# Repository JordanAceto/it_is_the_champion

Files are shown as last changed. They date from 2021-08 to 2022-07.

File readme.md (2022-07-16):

# 15 Watt Single Ended Tube Guitar Amp

- ## GU50 Pentode output
- ## Trainwreck style preamp
- ## It is the champion

---

## [SCHEMATIC](https://github.com/JordanAceto/it_is_the_champion/blob/main/pcb/docs/it_is_the_champion-schematic.pdf)

---
A prototype has been constructed and evaluated using a 6550 output tube. See the [prototype write up](https://github.com/JordanAceto/it_is_the_champion/blob/main/prototype/it_is_the_champion_prototype_write_up.pdf) for details. It sounds pretty good to me.

The GU50 output stage has been breadboarded. It seems to work well and gives a smidge more power out than the 6550 (I'm mostly just using it to be a hipster though).

Next steps:

Task | Status |
---------|--------------|
Schematic capture | &#9745;
PCB layout | &#9745;
Order boards and do test build | &#9745;
Front and rear panels | &#9745;
Generate complete BOM | &#9744;

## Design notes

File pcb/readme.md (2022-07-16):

# Kicad documents for the schematics and PCB layout

## The system consists of:
- ### Power supply PCB
- ### Preamp PCB
- ### Point to point wired power amp
- ### Chassis mount components (transformers, jacks, pots, etc)

The preamp and power supply pcbs are connected with breakaway mousebites.

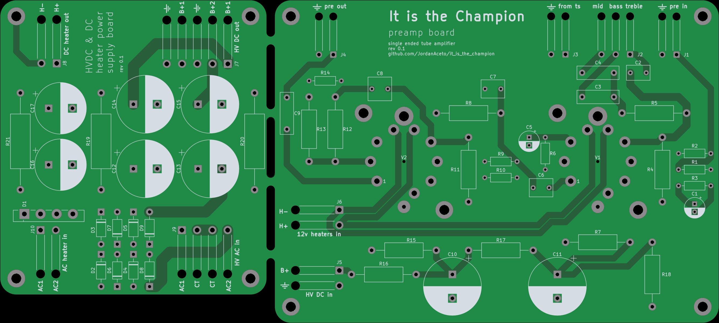
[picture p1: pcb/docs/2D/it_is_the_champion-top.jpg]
pcb


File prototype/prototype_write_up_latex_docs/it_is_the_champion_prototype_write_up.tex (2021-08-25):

\documentclass[pdftex,letterpaper,11pt]{article}
\usepackage[top=1in,bottom=1in,left=1in,right=1in]{geometry}

\usepackage[dvips]{graphicx}
\usepackage{amsmath}
\usepackage{amssymb}
\usepackage{color}
\usepackage[yyyymmdd]{datetime}
\usepackage{fancyhdr}
\usepackage{fancyvrb}
\usepackage[hidelinks]{hyperref}
\usepackage{pslatex}

\usepackage{subfig}
\usepackage{graphicx}
\usepackage[cache=false]{minted}

\usepackage{fancyhdr}
\usepackage{poemscol}
\usepackage{lmodern}

\pagestyle{fancy}

\title{%
	It is the Champion \\
	\large Prototype findings}

\author{Jordan Aceto}

\setlength{\parindent}{0mm}
\setlength{\parskip}{3mm}

\lfoot{Jordan Aceto}
\cfoot{Page \thepage}
\rfoot{PDF: \today, \currenttime}

\renewcommand{\footrulewidth}{0.4pt}

\begin{document}

\maketitle

\tableofcontents

\newpage

\section{Basic Features}

\begin{itemize}
\item Made of mostly ``junk box'' parts.
\item Single ended 6550 ouput stage, cathode biased.
\item Two 12AX7 tubes in the preamp.
\item Fairly high gain ``Trainwreck-ish'' preamp with four gain stages.
\item Conventional treble, middle, bass tone stack.
\item Gain and master volume controls.
\item Point to point wiring in a gutted Fender Vibro-Champ XD cabinet.
\item Power transformer: Hammond 276x.
\item Output transformer: Edcor GXSE15-8-3.5k
\item DC filaments for the first 12AX7, supplied by a separate Antek AN-0115 transformer.
\end{itemize}

\newpage

\section{Preamp}

The preamp is fairly similar to the ``Trainwreck'' circuit. It has the plate driven tone stack early on in the signal path, followed by a gain stage, and then a cold-clipper stage. Since this is a single ended amp without a phase inverter, an additional gain stage is used before the master volume for some extra crunch.

I tweaked some of the values in the tone stack, and added a treble-cut capacitor (C7) to tame some of the ``breaking glass'' high frequencies. This went into a combo with a Warehouse Speakers Veteran-10 10" speaker. The speaker is pretty bright already, so some of the tweaks were implemented to tame exessive treble. If a different speaker is used, I would recommend messing with the tone stack and frequency shaping components to taste.

\begin{figure}[H]
\centering
\caption{Pre-amp circuit}
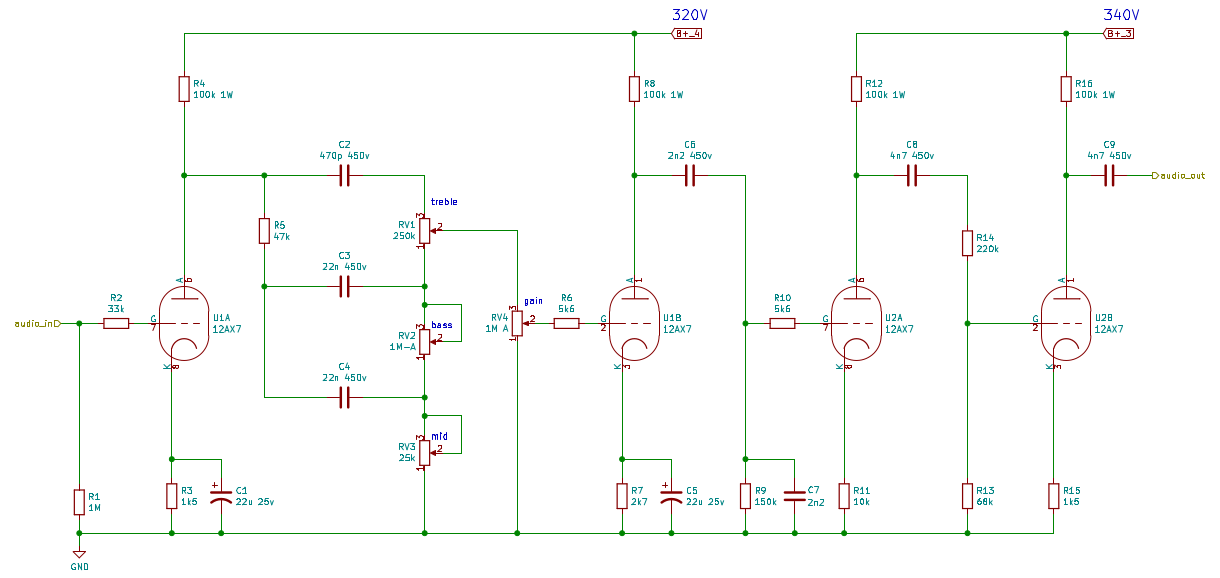
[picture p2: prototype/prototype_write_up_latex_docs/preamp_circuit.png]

\end{figure}

Notable features of this preamp are the tone shaping before the distortion, and small value coupling caps which shave bass frequencies. This circuit is pretty bright and ``cutting'', with enough gain for lots of preamp distortion. It can't quite do modern high-gain metal tones, but it does get pretty darn crunchy. It cleans up very well with the gain control set low, and using the volume control on your guitar is effective for doing the ``clean to mean'' thing. 

Both the clean and distorted tones sound great to me. It has lots of sustain and harmonic richness. It can tend towards overly bright and brittle tones, but adjusting the treble control, the tone pot on your guitar, and pick attack can mitigate this. The bright and cutting sounds can also help the guitar sit well in a mix.

\section{Power Amp}

The single 6550 output tube was chosen to provide a little more ``oomph'' than a typical Champ-style single ended amp, but still be fairly low power for playing at home or in the studio at reasonable volumes. I was looking for about 8 to 10 watts of clean output power, and about 15 watts when heavily overdriven.

\begin{figure}[H]
\centering
\caption{Power amp circuit}
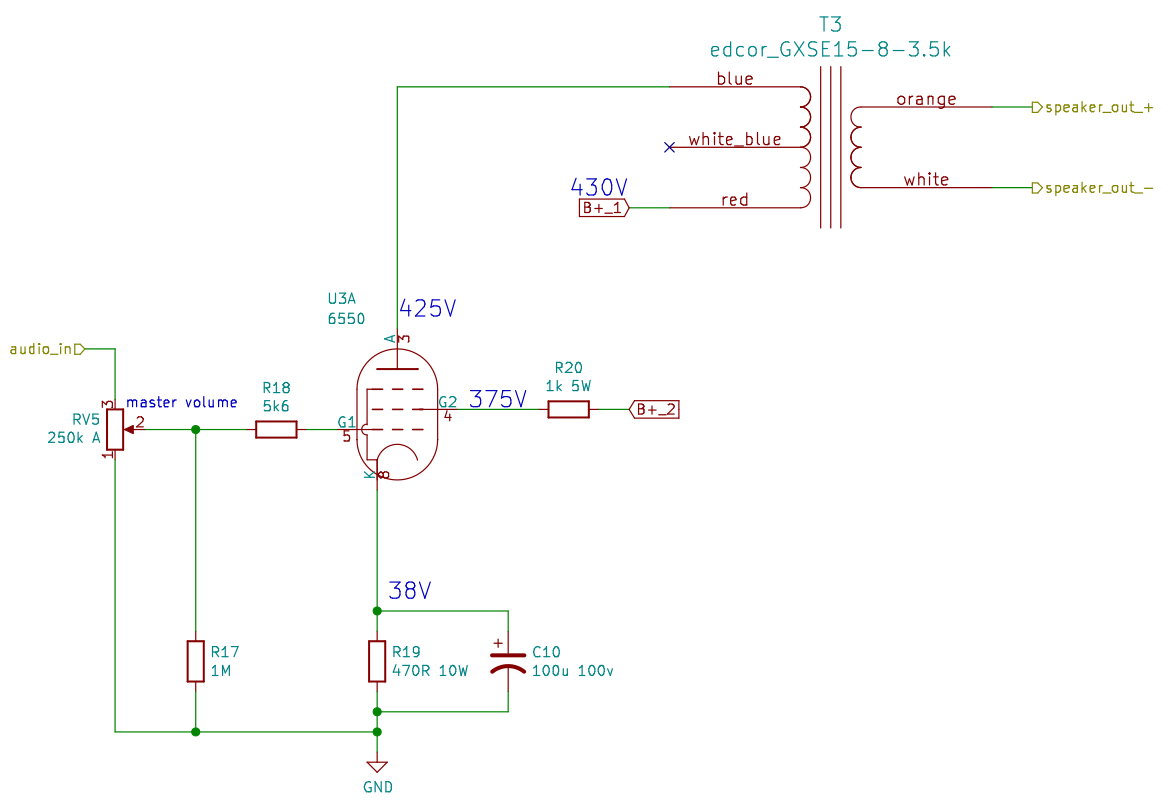
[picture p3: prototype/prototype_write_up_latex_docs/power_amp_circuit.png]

\end{figure}

As we can see by examining the voltage across the cathode resistor, about $80mA$ of bias current flows in the power tube at idle, for about 31 watts of dissipation. The maximum plate dissipation for this tube is 35 watts. I could probably bump up the bias current a little bit, there is no compelling reason to do so for now. 

Erring on the cold side will increase tube life and decrease heat in the chassis. Large output swings will be a little bit asymmetric and will introduce a little DC current in the output transformer, but the OT can handle it and a little asymmety sounds good for overdriven guitar sounds.

After construction, the amp was hooked up to a dummy load to test the power output. The output transformer has a 438:1 impedance ratio, and a variety of load resistances were tried out to experiment with the relationship between load impedance and power delivery. I have a big honkin' dummy load made up of a string of eight 2$\Omega$ resistors, and this allowed me to vary the load resistance, and thus the reflected primary impedance, by clipping heavy test leads across various resistors. The findings are summarized in the table below:

\begin{table}[H]
\centering
\begin{tabular}{ c | c | c }
    Load resistance  & Reflected impedance & Power out (Watts)  \\ \hline \hline
	4 & 1750 & 5.8 \\ \hline
	6 & 2628 & 8.5 \\ \hline
	8 & 3500 & 9.7 \\ \hline
	10 & 4380 & 10 \\ \hline
	12 & 5256 & 9.2 \\ \hline
	14 & 6132 & 8.8 \\ \hline
	16 & 7008 & 7.9 \\ \hline
\end{tabular}
\end{table}

The measured power output is an approximation and shouldn't be taken as a super precise measurement. I adjusted the signal to \textit{just} under the point of clipping while measuring the power output for each impedance, but this is a guitar amp and there is significant nonlinearity well below clipping. The exact point where ``clean signal'' stops and ``clipping'' begins is a soft and blurry line, but I tried to at least keep things reasonably consistent between readings. 

The above table shows us that somewhere around 3.5k to 5k is a happy primary impedance for this circuit if we want to get the most out of the setup as it is. The 3.5k$\Omega$ primary impedace from the output transformer I had lying around seems OK. With experimentation, we could tweak the B+ supply and the load to maximize power out, but a watt or two in either direction isn't going to make or break the amp.

The distortion introduced by overdriving the power amp is quite pleasant, with a gradual introduction of compression, then crunch, then heavy distortion. This is illustrated in the oscilloscope shots below:

\begin{figure}[H]
    \centering
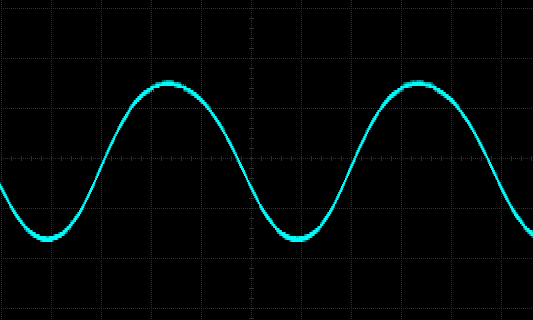
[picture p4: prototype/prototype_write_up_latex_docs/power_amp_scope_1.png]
    \subfloat[\centering]{{ }}
    \qquad
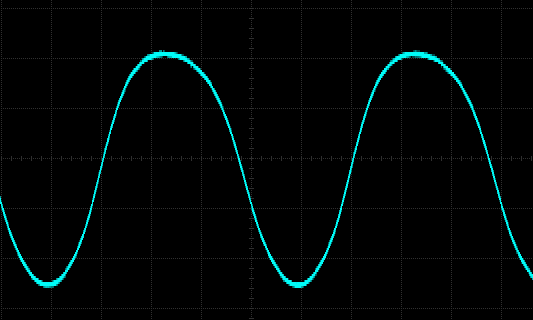
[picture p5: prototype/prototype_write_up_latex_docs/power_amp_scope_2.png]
    \subfloat[\centering]{{ }}
    
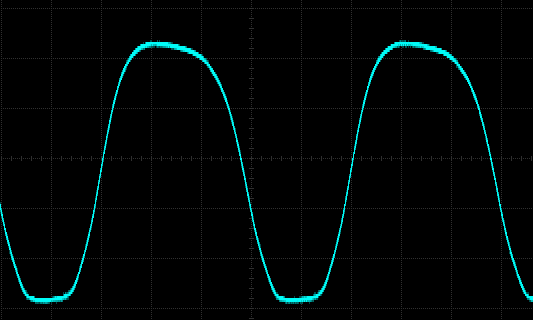
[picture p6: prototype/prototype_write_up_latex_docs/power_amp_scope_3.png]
    \subfloat[\centering]{{ }}
    \qquad
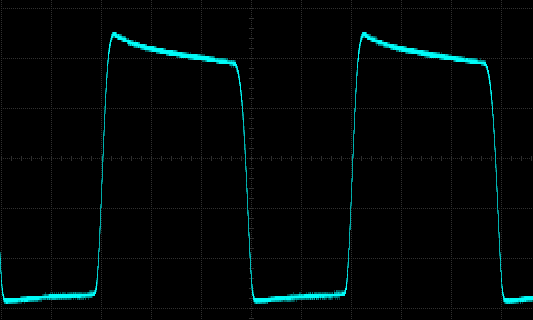
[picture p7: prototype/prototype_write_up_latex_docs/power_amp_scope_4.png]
    \subfloat[\centering]{{ }}
\end{figure}

The asymmetric nature of the distortion is mostly due to the somewhat cold bias current. To me, the circuit sounds good and hits the desired output power, so there is little motivation to try to bring it right into the center of class A or squeeze every last clean milliwatt out of it.

The final output power delivered into an 8 $\Omega$ load is about 10 watts at ``somewhere below five percent'' distortion, and about 15 watts when hard clipping, right on target. I don't have the equipment to accurately measure distortion, so the clean output was ``eyeballed''. IMO, this is good enough for guitar work.

\section{Power supply}

The basic power supply plan is fairly standard, but the power transformer was scavanged from the bin so I had to futz around a little bit. The Hammond power transformer used only has a 115 volt primary winding. This caused all of the secondary voltages to come out a bit high when fed from a modern 120 volt wall outlet. 

To keep the B+ reasonable and, more importantly, to keep the heater voltage in spec, I used the 5 volt winding in ``bucking'' configuration  in series with the primary to reduce all secondary voltages a little bit. Modern Hammond transformers have improved the primary windings to be more compatible with modern wall voltages, but this trick was used so that I could use up an old dust bin transformer which was otherwise suitable.

\begin{figure}[H]
\centering
\caption{Main power supply}
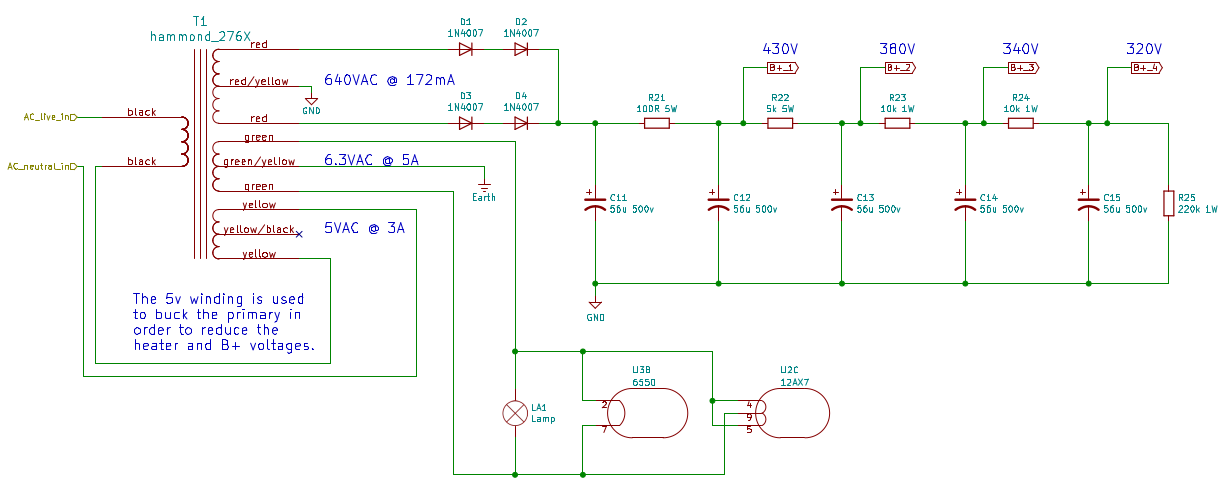
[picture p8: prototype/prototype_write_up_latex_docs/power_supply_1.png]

\end{figure}

After construction, the amp sounded pretty good and the noise performance was quite acceptable. But there was a small amount of 60/120Hz AC buzz coming from the first stage. Since there is so much gain in the preamp, a small amount of noise can become annoying when you crank the gain. I've heard much worse from popular amps, but since this is a hobby project I can afford to spend some effort improving the noise performance. To get things really quiet, I decided to use a DC heater supply for the first 12AX7 tube.

I initially tried to rectify the existing 6 volt winding and use the smoothed DC for just the first tube. This did improve the buzz coming from the first gain stage, but it worsened the buzz coming from the second preamp tube. This is a common problem when trying to do DC heaters as simply as possible, especially in a small chassis. The rectification causes the existing AC supply to become more distorted, and high frequency components are injected into the signal path.

To get things really quiet, I added a small transformer to create a DC heater supply just for V1. I used a small 15 volt transformer that I had kicking around for this. The 15 volts AC is fed into a bridge rectifier, then smoothed with a large capacitor, then fed into an RC filter wich provides further ripple reduction and drops the voltage to right around 12.6 volts DC when loaded with a single 12AX7 heater wired for 12 volt operation.

\begin{figure}[H]
\centering
\caption{DC heater supply for V1}
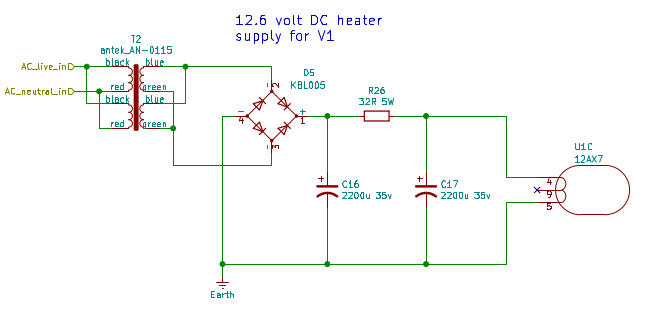
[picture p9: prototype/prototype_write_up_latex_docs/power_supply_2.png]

\end{figure}

With the first tube heater supplied by this smooth DC voltage generated from a different widing than the rest of the 6 volt AC heaters, the amp has very good noise performance. There is some white-noise-ish hiss and a very small amount of power line frequency buzz when the gain control and master volume are both set very high, but this is to be expected in any high gain tube circuit. Most importantly to me, the noise is dominated by hiss, with very low levels of 60 Hz related hum and buzz.

\section{Construction}

The amp was built in the carcass of a Fender Vibro-Champ XD amp that a local guitar store was throwing away. I stripped everything out of the chassis and drilled most of the threaded standoffs out.

The circuit is all point-to-point construction using terminal strips. The tubes are layed out so that the signal path is very straghtforward and signal wires don't meander all over the chassis. Noisy rectifiers and heaters are kept far from sensitive audio nodes.

\begin{figure}[H]
\centering
\caption{Guts}
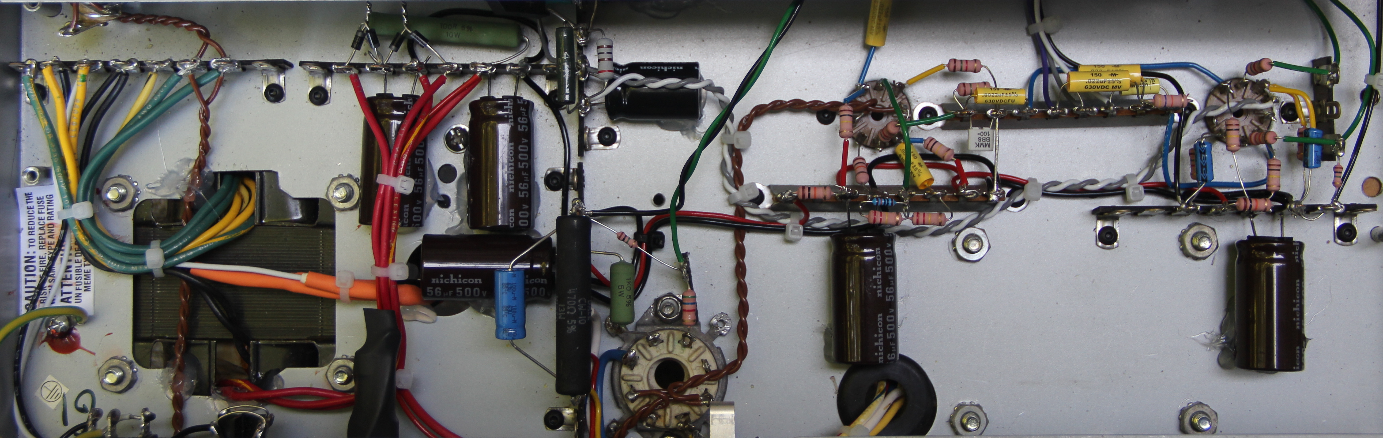
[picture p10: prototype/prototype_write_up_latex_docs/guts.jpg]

\end{figure}

The chassis does get quite hot. The 6550 power tube is dissipating around 30 watts, and its heat rises straight up into the chassis. There are a handful more watts inside the chassis, mostly in the cathode bias resistor for the power tube and the dropping resistor for the DC heater supply.

This is a tube amp though, so hot and toasty is to be expected. None of the components are overly stressed, and reliablility should be quite good. Due to the point-to-point construction, repairs and mods are somewhat annoying to perform, but infinitely possible.

The original Fender donor combo amp came with an 8" speaker, which is just too small for serious guitar sounds at all but the lowest volumes. Additionally, the baffle was made of really cheesy particle board. I made a new baffle out of decent 1/2" plywood with a cutout for a 10" speaker and reapplied the old grill cloth. The Warehouse Vet-10 10" speaker \textit{juuuuuust} fits, other speakers may or may not fit at all. 

The power tube is very close to the magnet, and the spring tube retainer I installed occasionally rattles sympathetically at loud volumes. This is not a major problem, I'll leave it for now and reasses if it becomes annoying later.

\section{Conclusion}

This prototype is a definte success. The noise performance is very good and the power output is right where I wanted it to be. The sound is very nice. There is a range of sparkly cleans, crunchy, and fuzzy sounds in there. The prototype would be perform very well as a practice amp at home, and would probably record pretty well.

The limiting factor is mainly the lame tiny MDF cabinet. Repurposing the dead Fender combo was economical, but a slightly larger cabinet made of better materials would be an improvement. The amp would be pretty at home in a Princeton sized cabinet if another one is made. This would allow for trying out different 10" speakers without worrying about the magnet coming into contact with the power tube.

The next step would be to build another version with selected, instead of stumbled upon, parts. I've layed out a pcb for the preamp and chosen some transformers that I think will work. Unfortunately this will probably be on hold for a while, as the semester is starting up and I won't have much time for fun hobbies until winter break.

\section{About the Name}

When I used to repair tube amplifiers, it was common for the various ``Champs'' to come through the shop for servicing. There is the Fender Champ, the Champion, the Vibro-Champ, the Super-Champ, the list goes on. Whenever I had one of these on my bench, I would always sing to it:

\begin{poem}
\begin{stanza}
You are the Champion\verseline
My frie-end\verseline
And you'll keep on fighting\verseline
Til the end\end{stanza}

\begin{stanza}
You are the Champion\verseline
You are the Champion\verseline
No time for losers\verseline
Cause you are the Champion\end{stanza}
... etc
\end{poem}

Since this amp roughly occupies ``Champ'' territory, only with more output power and with a much meatier preamp, naturally \textbf{It is the Champion}.

\end{document}

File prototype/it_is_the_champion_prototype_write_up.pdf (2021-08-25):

## It is the Champion

Prototype findings

Jordan Aceto

2021/08/25

## Contents

1 Basic Features | 2
2 Preamp | 2
3 Power Amp | 3
4 Power supply | 6
5 Construction | 7
6 Conclusion | 8
7 About the Name | 9

## 1 Basic Features

- Made of mostly “junk box” parts.
- Single ended 6550 ouput stage, cathode biased.
- Two 12AX7 tubes in the preamp.
- Fairly high gain “Trainwreck-ish” preamp with four gain stages.
- Conventional treble, middle, bass tone stack.
- Gain and master volume controls.
- Point to point wiring in a gutted Fender Vibro-Champ XD cabinet.
- Power transformer: Hammond 276x.
- Output transformer: Edcor GXSE15-8-3.5k
- DC filaments for the first 12AX7, supplied by a separate Antek AN-0115 transformer.
Jordan Aceto | Page 2 | PDF: 2021/08/25, 07:26

## 2 Preamp

The preamp is fairly similar to the “Trainwreck” circuit. It has the plate driven tone stack early on in the signal path, followed by a gain stage, and then a cold-clipper stage. Since this is a single ended amp without a phase inverter, an additional gain stage is used before the master volume for some extra crunch.

I tweaked some of the values in the tone stack, and added a treble-cut capacitor (C7) to tame some of the “breaking glass” high frequencies. This went into a combo with a Warehouse Speakers Veteran-10 10” speaker. The speaker is pretty bright already, so some of the tweaks were implemented to tame exessive treble. If a different speaker is used, I would recommend messing with the tone stack and frequency shaping components to taste.

Figure 1: Pre-amp circuit


Notable features of this preamp are the tone shaping before the distortion, and small value coupling caps which shave bass frequencies. This circuit is pretty bright and “cutting”, with enough gain for lots of preamp distortion. It can’t quite do modern high-gain metal tones, but it does get pretty darn crunchy. It cleans up very well with the gain control set low, and using the volume control on your guitar is effective for doing the “clean to mean” thing.

Both the clean and distorted tones sound great to me. It has lots of sustain and harmonic richness. It can tend towards overly bright and brittle tones, but adjusting the treble control, the tone pot on your guitar, and pick attack can mitigate this. The bright and cutting sounds can also help the guitar sit well in a mix.

Jordan Aceto | Page 3 | PDF: 2021/08/25, 07:26

## 3 Power Amp

The single 6550 output tube was chosen to provide a little more “oomph” than a typical Champ-style single ended amp, but still be fairly low power for playing at home or in the studio at reasonable volumes. I was looking for about 8 to 10 watts of clean output power, and about 15 watts when heavily overdriven.

Figure 2: Power amp circuit


As we can see by examining the voltage across the cathode resistor, about 80mA of bias current flows in the power tube at idle, for about 31 watts of dissipation. The maximum plate dissipation for this tube is 35 watts. I could probably bump up the bias current a little bit, there is no compelling reason to do so for now.

Erring on the cold side will increase tube life and decrease heat in the chassis. Large output swings will be a little bit asymmetric and will introduce a little DC current in the output transformer, but the OT can handle it and a little asymmety sounds good for overdriven guitar sounds.

After construction, the amp was hooked up to a dummy load to test the power output. The output transformer has a 438:1 impedance ratio, and a variety of load resistances were tried out to experiment with the relationship between load impedance and power delivery. I have a big honkin’ dummy load made up of a string of eight 2Ω resistors, and this allowed me to vary the load resistance, and thus the reflected primary impedance, by clipping heavy test leads across various

Jordan Aceto | Page 4 | PDF: 2021/08/25, 07:26

resistors. The findings are summarized in the table below:

Load resistance | Reflected impedance | Power out (Watts)
4 | 1750 | 5.8
6 | 2628 | 8.5
8 | 3500 | 9.7
10 | 4380 | 10
12 | 5256 | 9.2
14 | 6132 | 8.8
16 | 7008 | 7.9

The measured power output is an approximation and shouldn’t be taken as a super precise measurement. I adjusted the signal to just under the point of clipping while measuring the power output for each impedance, but this is a guitar amp and there is significant nonlinearity well below clipping. The exact point where “clean signal” stops and “clipping” begins is a soft and blurry line, but I tried to at least keep things reasonably consistent between readings.

The above table shows us that somewhere around 3.5k to 5k is a happy primary impedance for this circuit if we want to get the most out of the setup as it is. The 3.5kΩ primary impedace from the output transformer I had lying around seems OK. With experimentation, we could tweak the B+ supply and the load to maximize power out, but a watt or two in either direction isn’t going to make or break the amp.

The distortion introduced by overdriving the power amp is quite pleasant, with a gradual introduction of compression, then crunch, then heavy distortion. This is illustrated in the oscilloscope shots below:

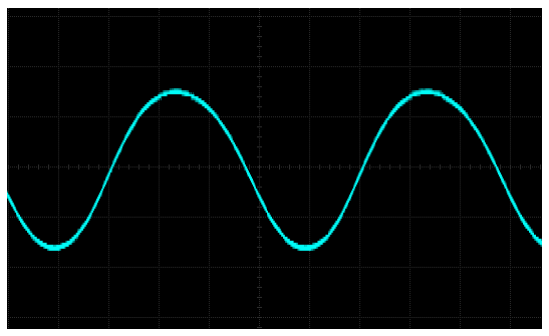
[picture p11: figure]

(a) (b)

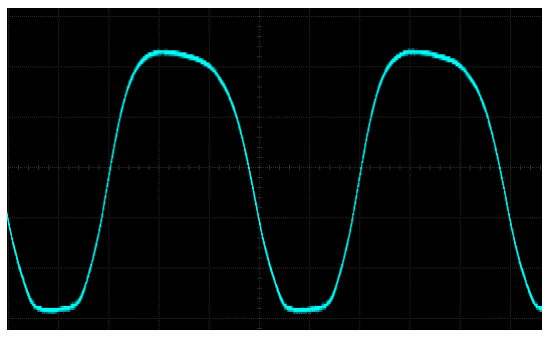
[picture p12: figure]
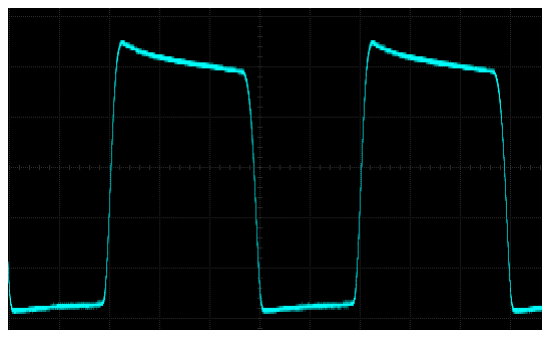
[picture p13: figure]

(c) (d)
Jordan Aceto | Page 5 | PDF: 2021/08/25, 07:26

The asymmetric nature of the distortion is mostly due to the somewhat cold bias current. To me, the circuit sounds good and hits the desired output power, so there is little motivation to try to bring it right into the center of class A or squeeze every last clean milliwatt out of it.

The final output power delivered into an 8 Ω load is about 10 watts at “somewhere below five percent” distortion, and about 15 watts when hard clipping, right on target. I don’t have the equipment to accurately measure distortion, so the clean output was “eyeballed”. IMO, this is good enough for guitar work.

## 4 Power supply

The basic power supply plan is fairly standard, but the power transformer was scavanged from the bin so I had to futz around a little bit. The Hammond power transformer used only has a 115 volt primary winding. This caused all of the secondary voltages to come out a bit high when fed from a modern 120 volt wall outlet.

To keep the B+ reasonable and, more importantly, to keep the heater voltage in spec, I used the 5 volt winding in “bucking” configuration in series with the primary to reduce all secondary voltages a little bit. Modern Hammond transformers have improved the primary windings to be more compatible with modern wall voltages, but this trick was used so that I could use up an old dust bin transformer which was otherwise suitable.

Figure 3: Main power supply

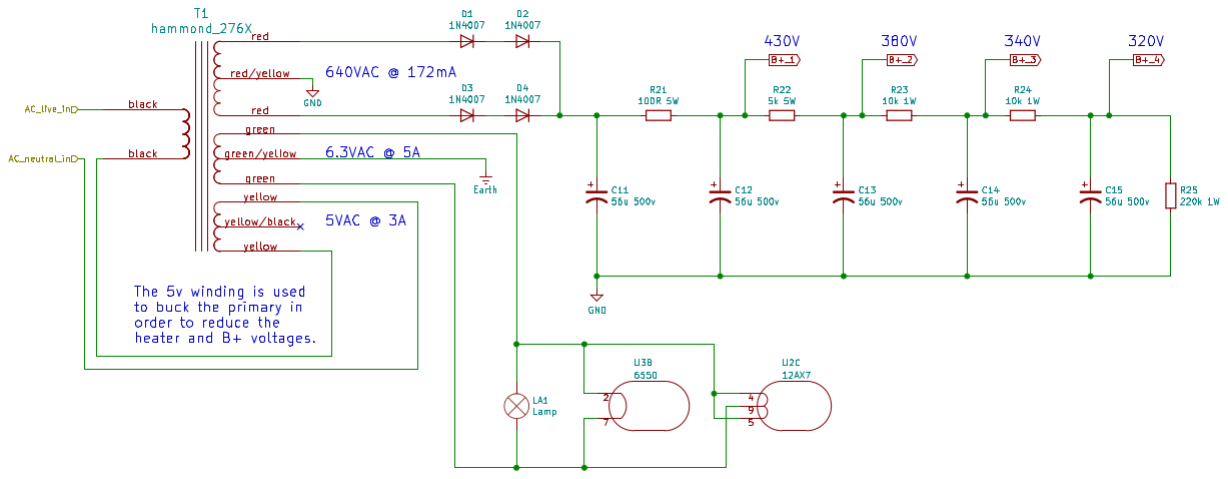
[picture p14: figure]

After construction, the amp sounded pretty good and the noise performance was quite acceptable. But there was a small amount of 60/120Hz AC buzz coming from the first stage. Since there is so much gain in the preamp, a small amount of noise can become annoying when you crank the gain. I’ve heard much worse from popular amps, but since this is a hobby project I can afford to spend some effort improving the noise performance. To get things really quiet, I decided to use a DC heater supply for the first 12AX7 tube.

I initially tried to rectify the existing 6 volt winding and use the smoothed DC for just the first

Jordan Aceto | Page 6 | PDF: 2021/08/25, 07:26

tube. This did improve the buzz coming from the first gain stage, but it worsened the buzz coming from the second preamp tube. This is a common problem when trying to do DC heaters as simply as possible, especially in a small chassis. The rectification causes the existing AC supply to become more distorted, and high frequency components are injected into the signal path.

To get things really quiet, I added a small transformer to create a DC heater supply just for V1. I used a small 15 volt transformer that I had kicking around for this. The 15 volts AC is fed into a bridge rectifier, then smoothed with a large capacitor, then fed into an RC filter wich provides further ripple reduction and drops the voltage to right around 12.6 volts DC when loaded with a single 12AX7 heater wired for 12 volt operation.

Figure 4: DC heater supply for V1


With the first tube heater supplied by this smooth DC voltage generated from a different widing than the rest of the 6 volt AC heaters, the amp has very good noise performance. There is some white-noise-ish hiss and a very small amount of power line frequency buzz when the gain control and master volume are both set very high, but this is to be expected in any high gain tube circuit. Most importantly to me, the noise is dominated by hiss, with very low levels of 60 Hz related hum and buzz.

## 5 Construction

The amp was built in the carcass of a Fender Vibro-Champ XD amp that a local guitar store was throwing away. I stripped everything out of the chassis and drilled most of the threaded standoffs out.

The circuit is all point-to-point construction using terminal strips. The tubes are layed out so that the signal path is very straghtforward and signal wires don’t meander all over the chassis. Noisy rectifiers and heaters are kept far from sensitive audio nodes.

Jordan Aceto | Page 7 | PDF: 2021/08/25, 07:26

Figure 5: Guts


The chassis does get quite hot. The 6550 power tube is dissipating around 30 watts, and its heat rises straight up into the chassis. There are a handful more watts inside the chassis, mostly in the cathode bias resistor for the power tube and the dropping resistor for the DC heater supply.

This is a tube amp though, so hot and toasty is to be expected. None of the components are overly stressed, and reliablility should be quite good. Due to the point-to-point construction, repairs and mods are somewhat annoying to perform, but infinitely possible.

The original Fender donor combo amp came with an 8” speaker, which is just too small for serious guitar sounds at all but the lowest volumes. Additionally, the baffle was made of really cheesy particle board. I made a new baffle out of decent 1/2” plywood with a cutout for a 10” speaker and reapplied the old grill cloth. The Warehouse Vet-10 10” speaker juuuuuust fits, other speakers may or may not fit at all.

The power tube is very close to the magnet, and the spring tube retainer I installed occasionally rattles sympathetically at loud volumes. This is not a major problem, I’ll leave it for now and reasses if it becomes annoying later.

## 6 Conclusion

This prototype is a definte success. The noise performance is very good and the power output is right where I wanted it to be. The sound is very nice. There is a range of sparkly cleans, crunchy, and fuzzy sounds in there. The prototype would be perform very well as a practice amp at home, and would probably record pretty well.

The limiting factor is mainly the lame tiny MDF cabinet. Repurposing the dead Fender combo was economical, but a slightly larger cabinet made of better materials would be an improvement. The amp would be pretty at home in a Princeton sized cabinet if another one is made. This would allow for trying out different 10” speakers without worrying about the magnet coming into contact with the power tube.

The next step would be to build another version with selected, instead of stumbled upon, parts. I’ve layed out a pcb for the preamp and chosen some transformers that I think will work. Unfortunately this will probably be on hold for a while, as the semester is starting up and I won’t have much time

Jordan Aceto | Page 8 | PDF: 2021/08/25, 07:26

for fun hobbies until winter break.

## 7 About the Name

When I used to repair tube amplifiers, it was common for the various “Champs” to come through the shop for servicing. There is the Fender Champ, the Champion, the Vibro-Champ, the Super-Champ, the list goes on. Whenever I had one of these on my bench, I would always sing to it:

You are the Champion
My frie-end
And you’ll keep on fighting Til the end

You are the Champion
You are the Champion
No time for losers
Cause you are the Champion

... etc

Since this amp roughly occupies “Champ” territory, only with more output power and with a much meatier preamp, naturally It is the Champion.

Jordan Aceto | Page 9 | PDF: 2021/08/25, 07:26

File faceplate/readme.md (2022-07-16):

# Cheap and cheerful faceplate option

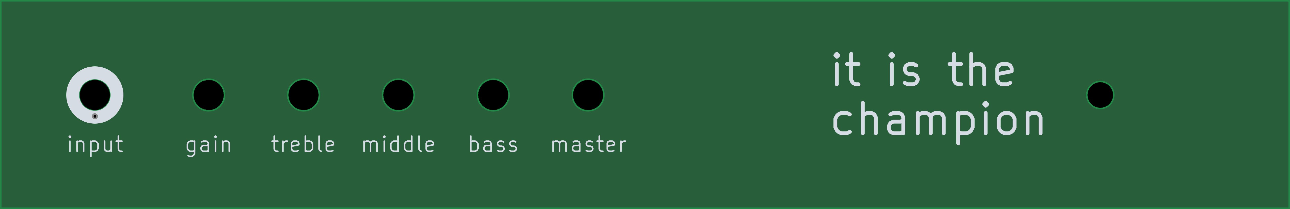
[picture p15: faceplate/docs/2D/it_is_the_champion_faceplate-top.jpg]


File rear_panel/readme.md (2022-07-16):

# Cheap and cheerful rear panel option

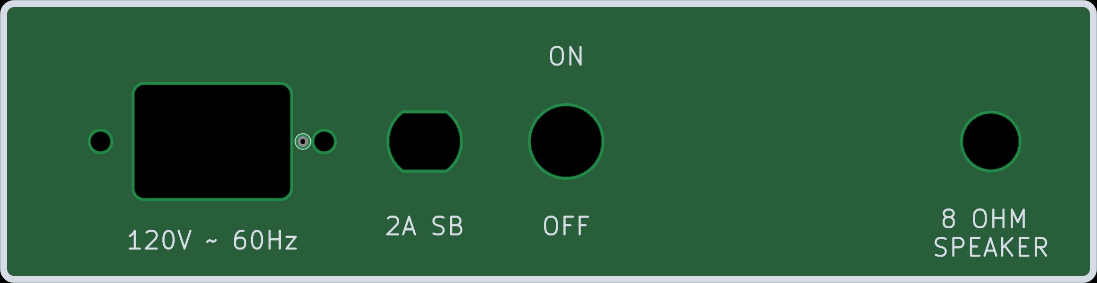
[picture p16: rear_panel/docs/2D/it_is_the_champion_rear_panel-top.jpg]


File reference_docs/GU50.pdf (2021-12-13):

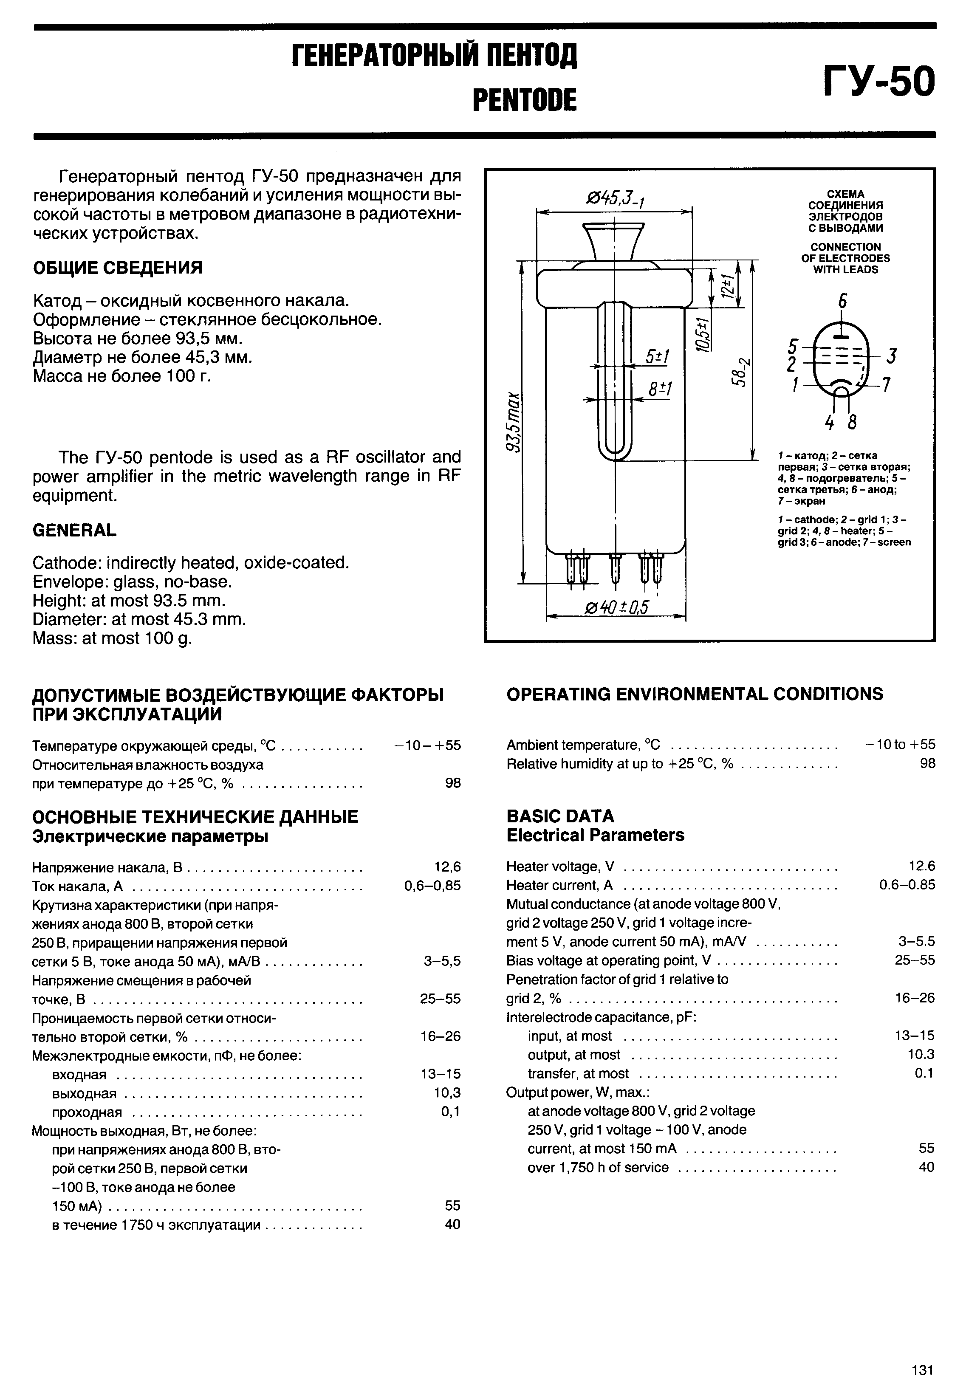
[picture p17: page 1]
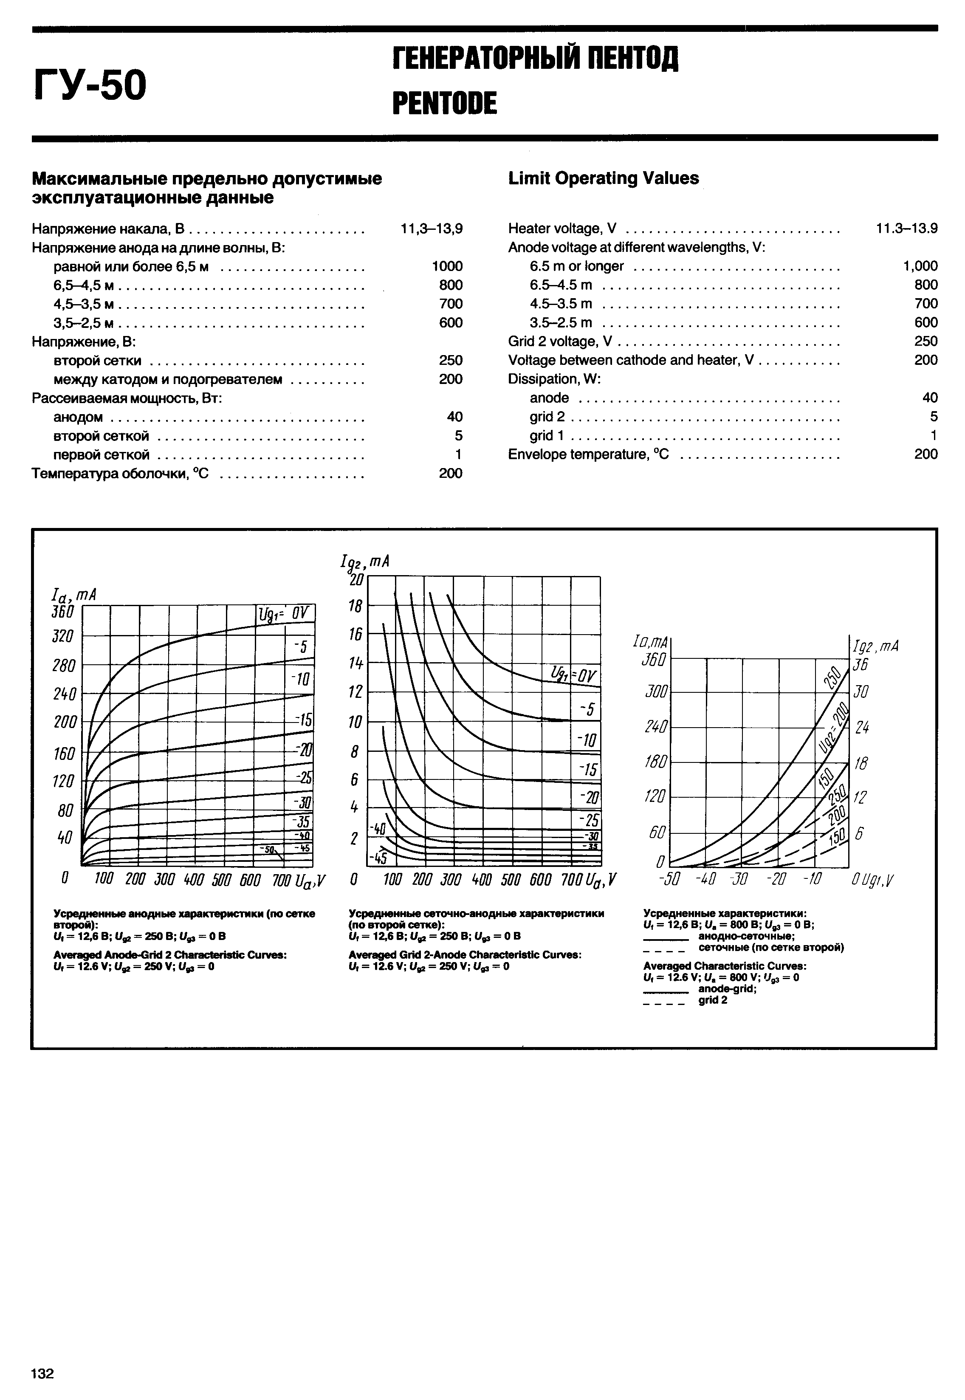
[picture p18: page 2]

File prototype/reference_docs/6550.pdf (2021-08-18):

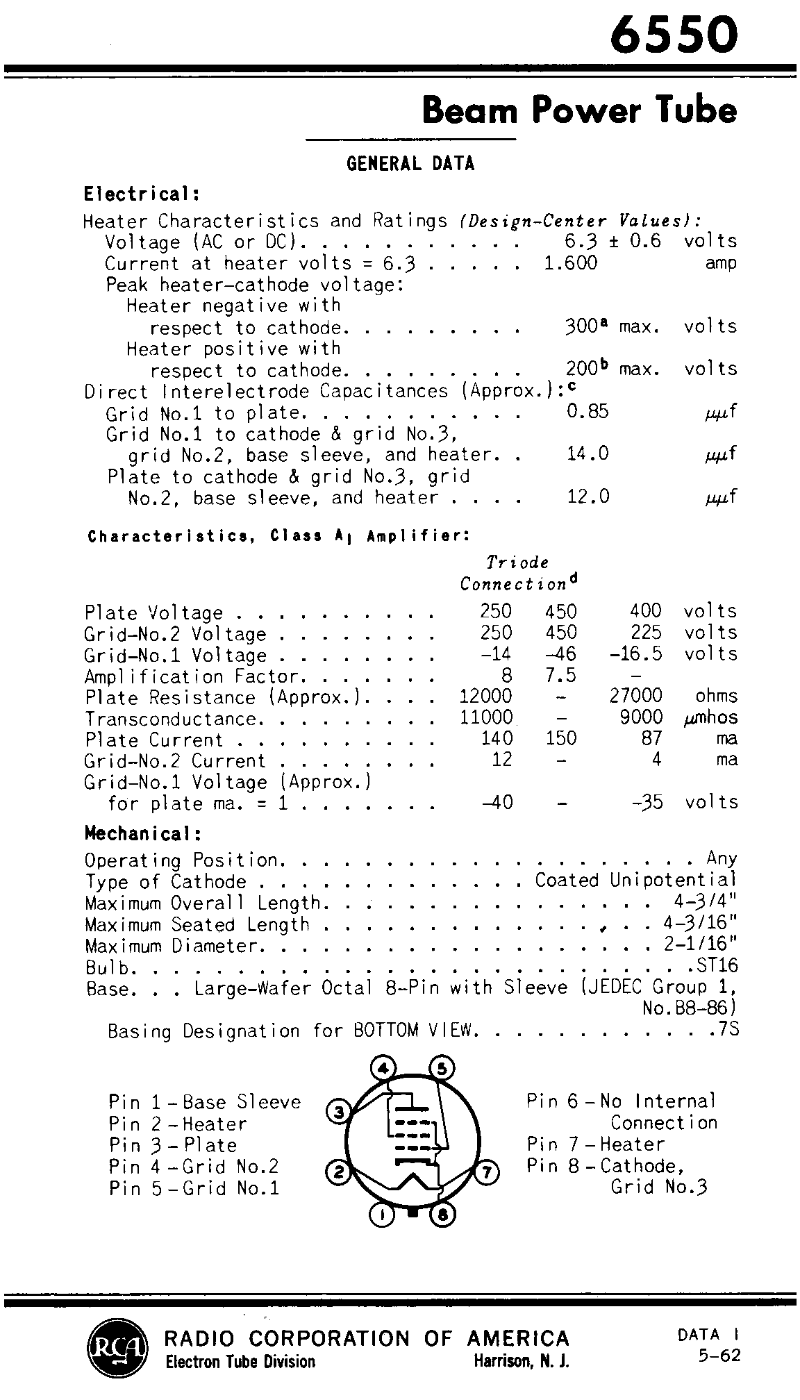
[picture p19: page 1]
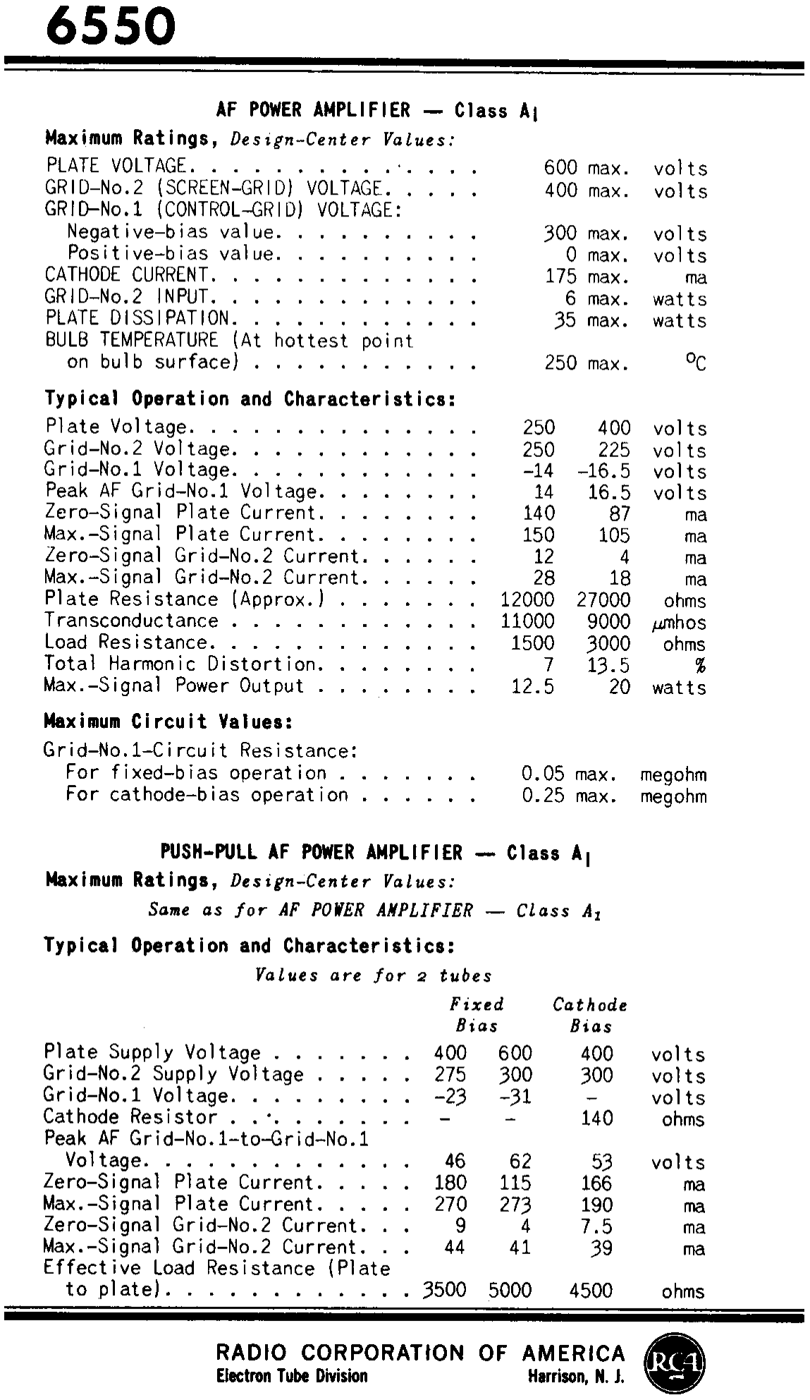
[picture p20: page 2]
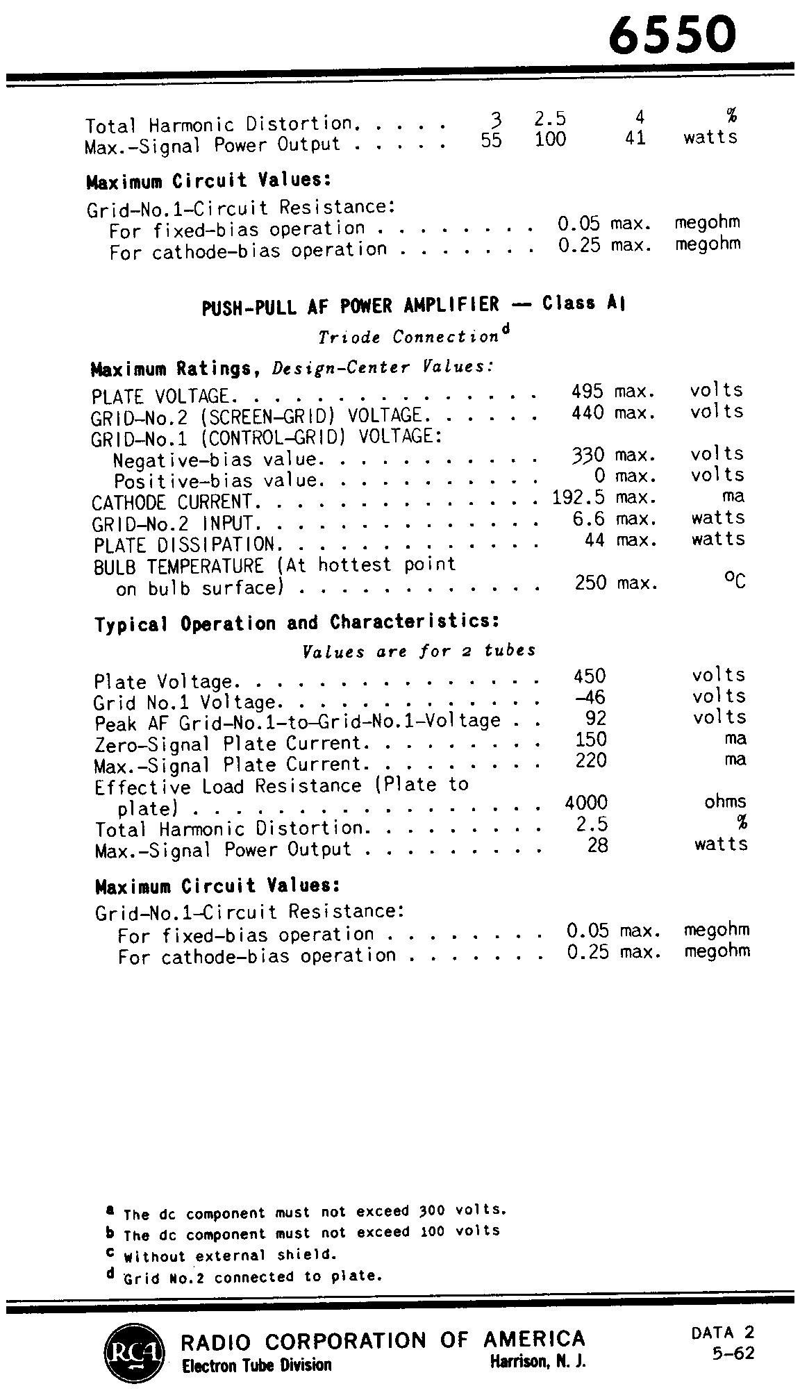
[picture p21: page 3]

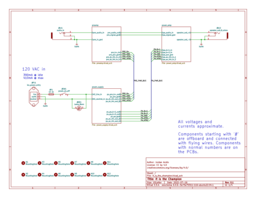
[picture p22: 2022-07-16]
pcb/docs/html_nav/images/cat_Schematic_it_is_the_champion-schematic.png

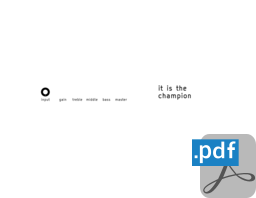
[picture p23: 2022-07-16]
faceplate/docs/html_nav/images/cat_pdf_layers_it_is_the_champion_faceplate-F_Silkscreen.png

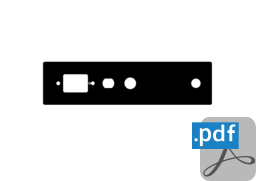
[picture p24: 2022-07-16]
rear_panel/docs/html_nav/images/cat_pdf_layers_it_is_the_champion_rear_panel-B_Cu.png

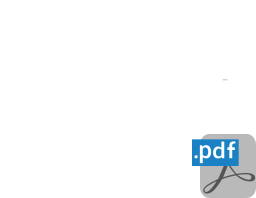
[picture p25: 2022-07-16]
faceplate/docs/html_nav/images/cat_pdf_layers_it_is_the_champion_faceplate-B_Silkscreen.png

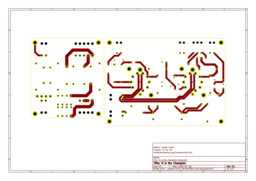
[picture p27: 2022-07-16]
pcb/docs/html_nav/images/cat_PCB_it_is_the_champion-F_Cu.png

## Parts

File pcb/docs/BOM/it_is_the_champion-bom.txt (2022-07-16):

Row	Description	Part	References	Value	Footprint	Quantity Per PCB	Status	Datasheet
1	Unpolarized capacitor	C	C2	470p WIMA FKP2	C_Rect_L7.2mm_W4.5mm_P5.00mm_FKS2_FKP2_MKS2_MKP2	1	 	~
2	Unpolarized capacitor	C	C6 C7	2n2 WIMA FKP2	C_Rect_L7.2mm_W5.5mm_P5.00mm_FKS2_FKP2_MKS2_MKP2	2	 	~
3	Unpolarized capacitor	C	C8	4n7 WIMA FKP2	C_Rect_L7.2mm_W7.2mm_P5.00mm_FKS2_FKP2_MKS2_MKP2	1	 	~
4	Unpolarized capacitor	C	C3 C4 C9	22n WIMA MKP4	C_Rect_L13.0mm_W4.0mm_P10.00mm_FKS3_FKP3_MKS4	3	 	~
5	Polarized capacitor	C_Polarized	C1 C5	22u 25v	CP_Radial_D6.3mm_P2.50mm	2	 	~
6	Polarized capacitor	C_Polarized	C10 C11	22u 450v	CP_Radial_D18.0mm_P7.50mm	2	 	~
7	Polarized capacitor	C_Polarized	C12 C13 C14 C15	220u 350v	CP_Radial_D18.0mm_P7.50mm	4	 	~
8	Polarized capacitor	C_Polarized	C16 C17	4700u 25v	CP_Radial_D16.0mm_P7.50mm	2	 	~
9	1000V 1A General Purpose Rectifier Diode, DO-41	1N4007	D2 D3 D4 D5 D6 D7 D8 D9	1N4007	D_DO-41_SOD81_P10.16mm_Horizontal	8	 	http://www.vishay.com/docs/88503/1n4001.pdf
10	Single-Phase Bridge Rectifier, 700V Vrms, 4.0A If, GBU package	GBU4M	D1	GBU4M	Diode_Bridge_Vishay_GBU	1	 	http://www.vishay.com/docs/88656/gbu4a.pdf
11	Resistor	R	R21	13R 5W	R_Axial_DIN0617_L17.0mm_D6.0mm_P30.48mm_Horizontal	1	 	~
12	Resistor	R	R19 R20	100R 5W	R_Axial_DIN0617_L17.0mm_D6.0mm_P30.48mm_Horizontal	2	 	~
13	Resistor	R	R3 R14	1k5	R_Axial_DIN0207_L6.3mm_D2.5mm_P10.16mm_Horizontal	2	 	~
14	Resistor	R	R6	2k7	R_Axial_DIN0207_L6.3mm_D2.5mm_P10.16mm_Horizontal	1	 	~
15	Resistor	R	R9	5k6	R_Axial_DIN0207_L6.3mm_D2.5mm_P10.16mm_Horizontal	1	 	~
16	Resistor	R	R10	10k	R_Axial_DIN0207_L6.3mm_D2.5mm_P10.16mm_Horizontal	1	 	~
17	Resistor	R	R17	10k 1W	R_Axial_DIN0414_L11.9mm_D4.5mm_P20.32mm_Horizontal	1	 	~
18	Resistor	R	R2	33k	R_Axial_DIN0207_L6.3mm_D2.5mm_P10.16mm_Horizontal	1	 	~
19	Resistor	R	R5 R16	47k 1W	R_Axial_DIN0414_L11.9mm_D4.5mm_P20.32mm_Horizontal	2	 	~
20	Resistor	R	R13	68k 1W	R_Axial_DIN0414_L11.9mm_D4.5mm_P20.32mm_Horizontal	1	 	~
21	Resistor	R	R4 R7 R11 R15	100k 1W	R_Axial_DIN0414_L11.9mm_D4.5mm_P20.32mm_Horizontal	4	 	~
22	Resistor	R	R8	150k 1W	R_Axial_DIN0414_L11.9mm_D4.5mm_P20.32mm_Horizontal	1	 	~
23	Resistor	R	R12 R18	220k 1W	R_Axial_DIN0414_L11.9mm_D4.5mm_P20.32mm_Horizontal	2	 	~
24	Resistor	R	R1	1M	R_Axial_DIN0207_L6.3mm_D2.5mm_P10.16mm_Horizontal	1	 	~
25		12AX7	V1 V2	12AX7	belton_VT9-PT-C	2	 	

Project info:
Schematic:	it_is_the_champion
Variant:	default
Revision:	0.1
Date:	2022-07-16
KiCad Version:	6.0.6-3a73a75311~116~ubuntu22.04.1
Statistics:
Component Groups:	25
Component Count:	49 (0 SMD/ 47 THT)
Fitted Components:	49 (0 SMD/ 47 THT)
Number of PCBs:	1
Total Components:	49

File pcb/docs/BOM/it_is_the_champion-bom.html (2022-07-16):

 | KiBot Bill of Materials
 | Schematic: it_is_the_champion Variant: default Revision: 0.1 Date: 2022-07-16 KiCad Version: 6.0.6-3a73a75311~116~ubuntu22.04.1 | Component Groups: 25 Component Count: 49 (0 SMD/ 47 THT) (per PCB) Fitted Components: 49 (0 SMD/ 47 THT) (per PCB) Number of PCBs: 1 Total Components: 49 (for 1 PCBs)
Row | Description | Part | References | Value | Footprint | Quantity Per PCB | Status | Datasheet
1 | Unpolarized capacitor | C | C2 | 470p WIMA FKP2 | C_Rect_L7.2mm_W4.5mm_P5.00mm_FKS2_FKP2_MKS2_MKP2 | 1 |  | ~
2 | Unpolarized capacitor | C | C6 C7 | 2n2 WIMA FKP2 | C_Rect_L7.2mm_W5.5mm_P5.00mm_FKS2_FKP2_MKS2_MKP2 | 2 |  | ~
3 | Unpolarized capacitor | C | C8 | 4n7 WIMA FKP2 | C_Rect_L7.2mm_W7.2mm_P5.00mm_FKS2_FKP2_MKS2_MKP2 | 1 |  | ~
4 | Unpolarized capacitor | C | C3 C4 C9 | 22n WIMA MKP4 | C_Rect_L13.0mm_W4.0mm_P10.00mm_FKS3_FKP3_MKS4 | 3 |  | ~
5 | Polarized capacitor | C_Polarized | C1 C5 | 22u 25v | CP_Radial_D6.3mm_P2.50mm | 2 |  | ~
6 | Polarized capacitor | C_Polarized | C10 C11 | 22u 450v | CP_Radial_D18.0mm_P7.50mm | 2 |  | ~
7 | Polarized capacitor | C_Polarized | C12 C13 C14 C15 | 220u 350v | CP_Radial_D18.0mm_P7.50mm | 4 |  | ~
8 | Polarized capacitor | C_Polarized | C16 C17 | 4700u 25v | CP_Radial_D16.0mm_P7.50mm | 2 |  | ~
9 | 1000V 1A General Purpose Rectifier Diode, DO-41 | 1N4007 | D2 D3 D4 D5 D6 D7 D8 D9 | 1N4007 | D_DO-41_SOD81_P10.16mm_Horizontal | 8 |  | http://www.vishay.com/docs/88503/1n4001.pdf
10 | Single-Phase Bridge Rectifier, 700V Vrms, 4.0A If, GBU package | GBU4M | D1 | GBU4M | Diode_Bridge_Vishay_GBU | 1 |  | http://www.vishay.com/docs/88656/gbu4a.pdf
11 | Resistor | R | R21 | 13R 5W | R_Axial_DIN0617_L17.0mm_D6.0mm_P30.48mm_Horizontal | 1 |  | ~
12 | Resistor | R | R19 R20 | 100R 5W | R_Axial_DIN0617_L17.0mm_D6.0mm_P30.48mm_Horizontal | 2 |  | ~
13 | Resistor | R | R3 R14 | 1k5 | R_Axial_DIN0207_L6.3mm_D2.5mm_P10.16mm_Horizontal | 2 |  | ~
14 | Resistor | R | R6 | 2k7 | R_Axial_DIN0207_L6.3mm_D2.5mm_P10.16mm_Horizontal | 1 |  | ~
15 | Resistor | R | R9 | 5k6 | R_Axial_DIN0207_L6.3mm_D2.5mm_P10.16mm_Horizontal | 1 |  | ~
16 | Resistor | R | R10 | 10k | R_Axial_DIN0207_L6.3mm_D2.5mm_P10.16mm_Horizontal | 1 |  | ~
17 | Resistor | R | R17 | 10k 1W | R_Axial_DIN0414_L11.9mm_D4.5mm_P20.32mm_Horizontal | 1 |  | ~
18 | Resistor | R | R2 | 33k | R_Axial_DIN0207_L6.3mm_D2.5mm_P10.16mm_Horizontal | 1 |  | ~
19 | Resistor | R | R5 R16 | 47k 1W | R_Axial_DIN0414_L11.9mm_D4.5mm_P20.32mm_Horizontal | 2 |  | ~
20 | Resistor | R | R13 | 68k 1W | R_Axial_DIN0414_L11.9mm_D4.5mm_P20.32mm_Horizontal | 1 |  | ~
21 | Resistor | R | R4 R7 R11 R15 | 100k 1W | R_Axial_DIN0414_L11.9mm_D4.5mm_P20.32mm_Horizontal | 4 |  | ~
22 | Resistor | R | R8 | 150k 1W | R_Axial_DIN0414_L11.9mm_D4.5mm_P20.32mm_Horizontal | 1 |  | ~
23 | Resistor | R | R12 R18 | 220k 1W | R_Axial_DIN0414_L11.9mm_D4.5mm_P20.32mm_Horizontal | 2 |  | ~
24 | Resistor | R | R1 | 1M | R_Axial_DIN0207_L6.3mm_D2.5mm_P10.16mm_Horizontal | 1 |  | ~
25 |  | 12AX7 | V1 V2 | 12AX7 | belton_VT9-PT-C | 2
Color reference:
KiCad Fields (default)
Generated Fields
User Fields
Empty Fields

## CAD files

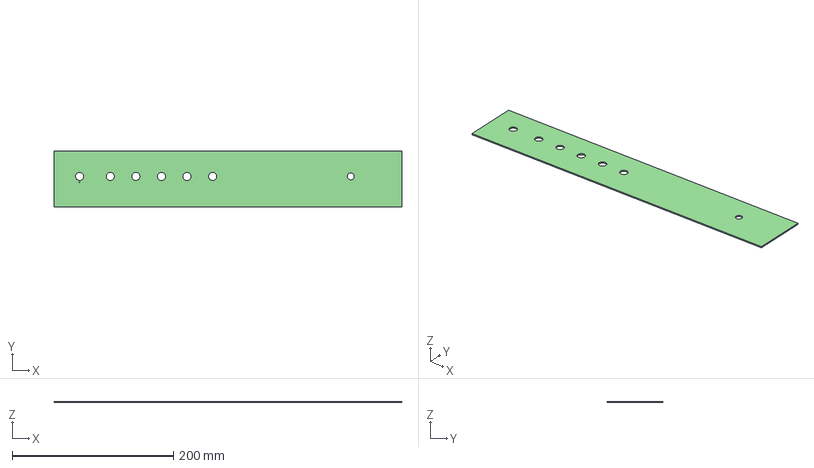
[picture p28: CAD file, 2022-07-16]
faceplate/docs/CAD/it_is_the_champion_faceplate-3D.step
431.8 x 69.8 x 1.60 mm

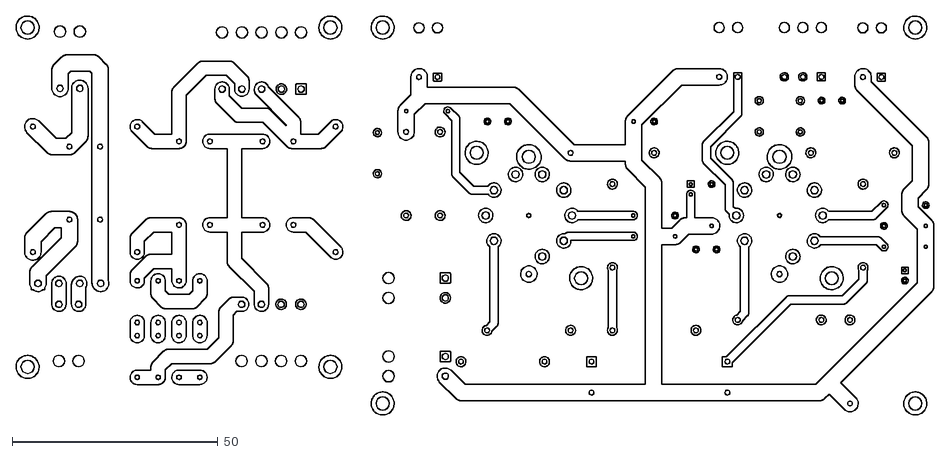
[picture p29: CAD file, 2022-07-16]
pcb/docs/CAD/it_is_the_champion-B_Cu.dxf
223.2 x 97.0

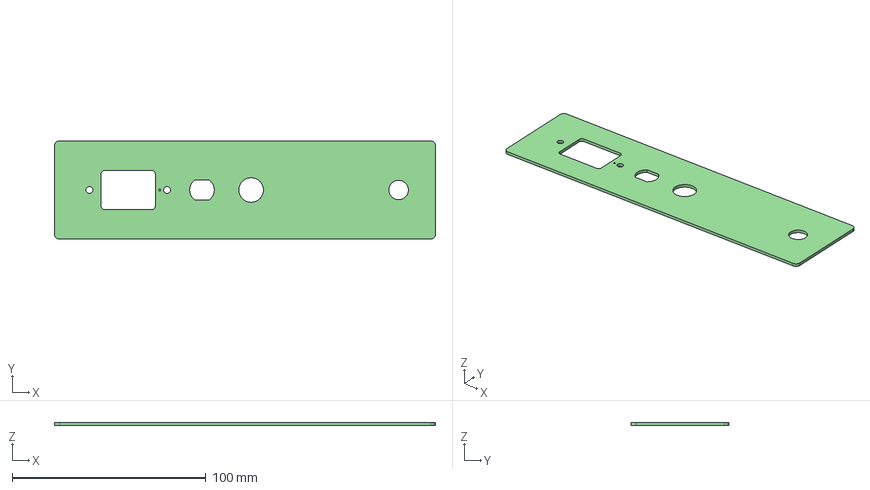
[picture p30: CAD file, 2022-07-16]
rear_panel/docs/CAD/it_is_the_champion_rear_panel-3D.step
196.8 x 50.8 x 1.60 mm

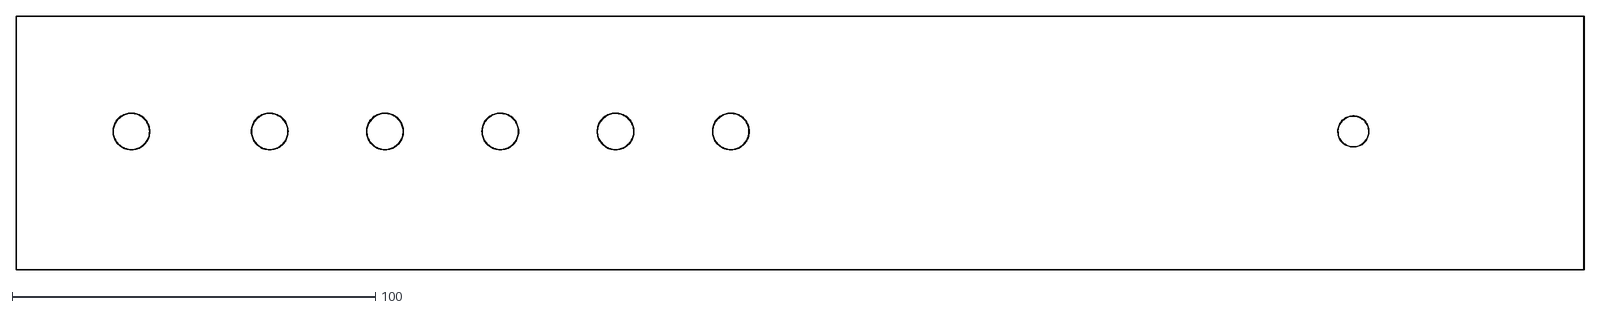
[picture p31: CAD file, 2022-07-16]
faceplate/docs/CAD/it_is_the_champion_faceplate-Edge_Cuts.dxf
431.9 x 69.9

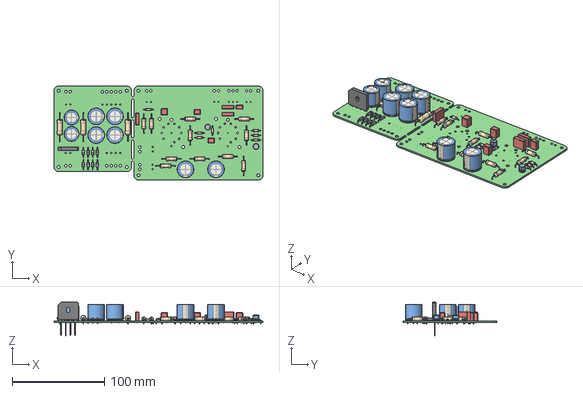
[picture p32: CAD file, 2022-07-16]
pcb/docs/CAD/it_is_the_champion-3D.step
226.1 x 101.6 x 36.4 mm
it_is_the_champion PCB

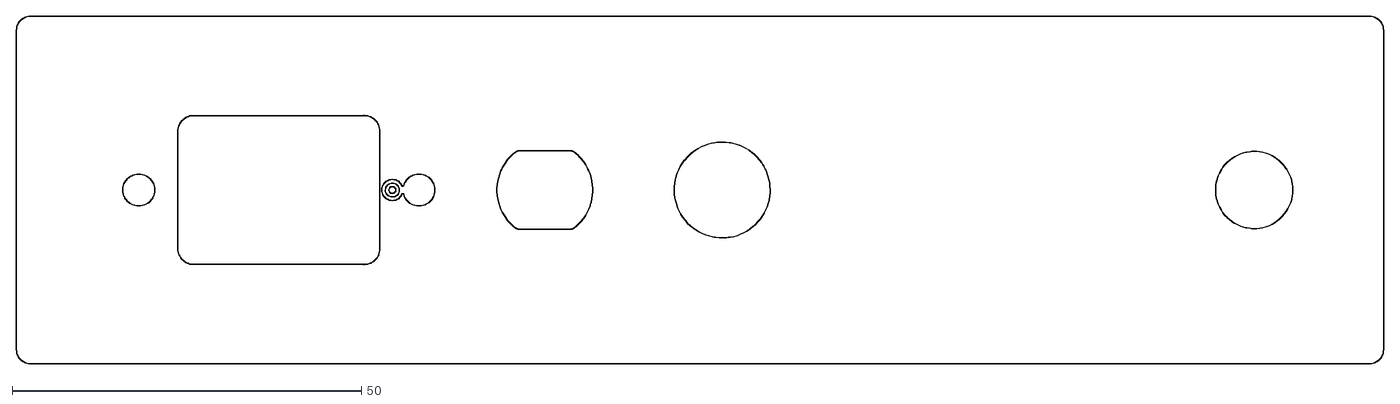
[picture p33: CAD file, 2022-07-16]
rear_panel/docs/CAD/it_is_the_champion_rear_panel-F_Cu.dxf
195.8 x 49.8

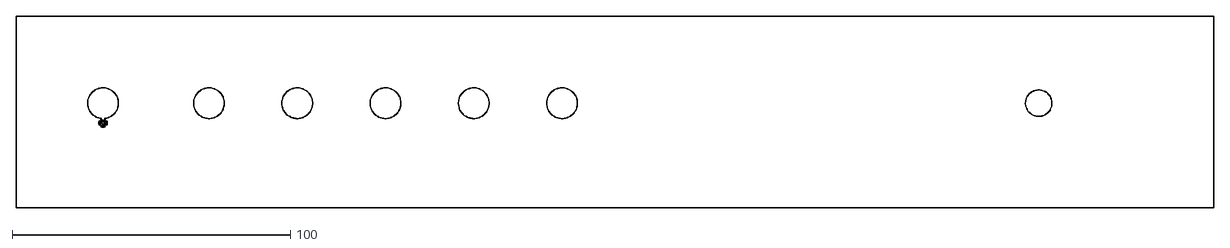
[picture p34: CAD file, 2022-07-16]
faceplate/docs/CAD/it_is_the_champion_faceplate-B_Cu.dxf
430.8 x 68.8

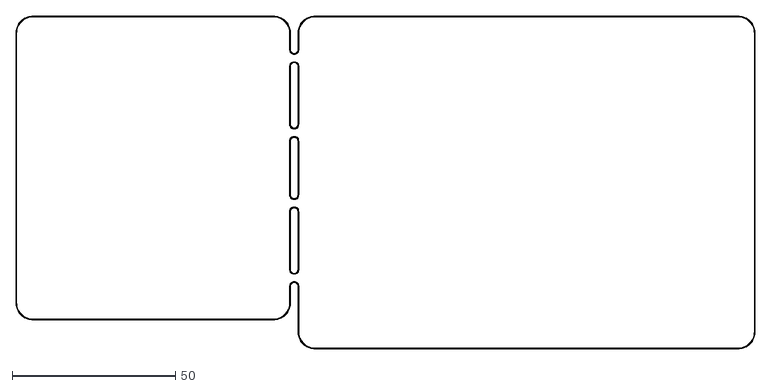
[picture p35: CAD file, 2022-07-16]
pcb/docs/CAD/it_is_the_champion-Edge_Cuts.dxf
226.2 x 101.7

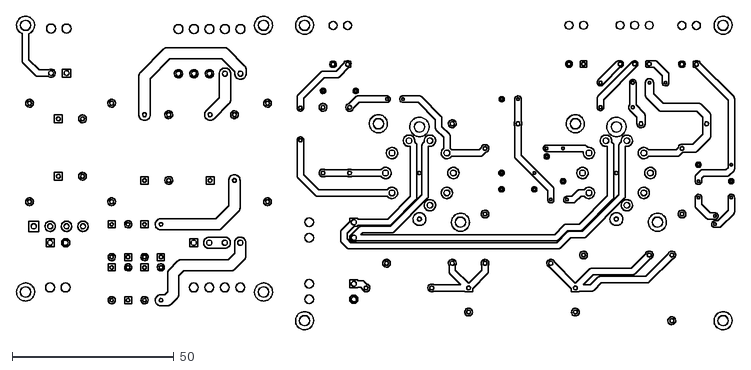
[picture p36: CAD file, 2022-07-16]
pcb/docs/CAD/it_is_the_champion-F_Cu.dxf
222.2 x 97.0

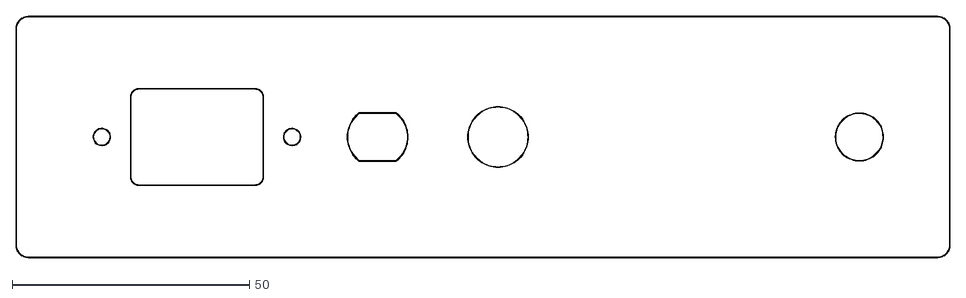
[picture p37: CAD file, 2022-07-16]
rear_panel/docs/CAD/it_is_the_champion_rear_panel-Edge_Cuts.dxf
196.9 x 50.8

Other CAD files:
faceplate/docs/CAD/it_is_the_champion_faceplate-B_Silkscreen.dxf
faceplate/docs/CAD/it_is_the_champion_faceplate-F_Silkscreen.dxf
pcb/docs/CAD/it_is_the_champion-B_Mask.dxf
pcb/docs/CAD/it_is_the_champion-B_Silkscreen.dxf
pcb/docs/CAD/it_is_the_champion-F_Mask.dxf
pcb/docs/CAD/it_is_the_champion-F_Silkscreen.dxf
rear_panel/docs/CAD/it_is_the_champion_rear_panel-B_Silkscreen.dxf
rear_panel/docs/CAD/it_is_the_champion_rear_panel-F_Silkscreen.dxf

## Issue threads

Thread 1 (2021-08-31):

Front panel pilot light hole is a little wonky

JordanAceto, 2021-08-31:
The pilot light hole on the front panel is slightly too big, and slightly too far to the left relative to the other holes.

Note that the left/right spacing of the hole is determined by the Fender Vibro-Champ DX chassis that I gutted and built the prototype in. If you are not building them in to dead Fender amps, then there is no huge reason to change the horizontal spacing.

The hole size should still be adjusted though, so you don't need a washer for the pilot light assembly.

JordanAceto, 2021-12-31:
New versions won't use this faceplate.

Closed 2021-12-31.

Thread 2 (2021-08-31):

Resistor footprints could be smaller

JordanAceto, 2021-08-31:
The resistor footprints are all the same, and all pretty large.

It's ok to oversize them, there are not that many so it won't be a huge price hit, and there are some benefits to larger than necessary resistors (it will get hot in there, so overrating is ok, and big packages make it easy to route traces under them, etc).

But still, some of them are a little silly, like the 1Meg tie down that has a footprint of a 2 or 3 watt resistor. C'mon.

You could change the footprints for many of the resistors to smaller ones, and maybe shave a square inch or two off the pcb.

Closed 2021-12-13.

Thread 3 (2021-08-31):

There should be standoffs near the 9-pin tube sockets

JordanAceto, 2021-08-31:
The Belton 9-pin PCB mount tube sockets have a soldered in support structure, and a hex standoff which affix them to the PCB.

In addition to these supports, there should be one or two standoffs between the PCB and the metal chassis right near the tube sockets. This will reduce flexing when tubes are inserted and removed.

Closed 2021-12-13.

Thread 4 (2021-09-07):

both preamp tube heaters should be run from the DC heater supply

JordanAceto, 2021-09-07:
In the first pcb rev, the first 12AX7 tube heater supply is DC, while the second one is run from a separate AC heater winding. Why not just run them both from the DC supply, assuming that you can get the desired level of smoothing? Try it out and see.

There is probably no huge performance increase to be had, as running V1 with DC heaters already kills most of the heater noise, but it would make wiring tidier with only one set of heater wires connected to the pcb. It would also get rid of the silly hum balance trimmer that does almost nothing.

Closed 2021-12-13.

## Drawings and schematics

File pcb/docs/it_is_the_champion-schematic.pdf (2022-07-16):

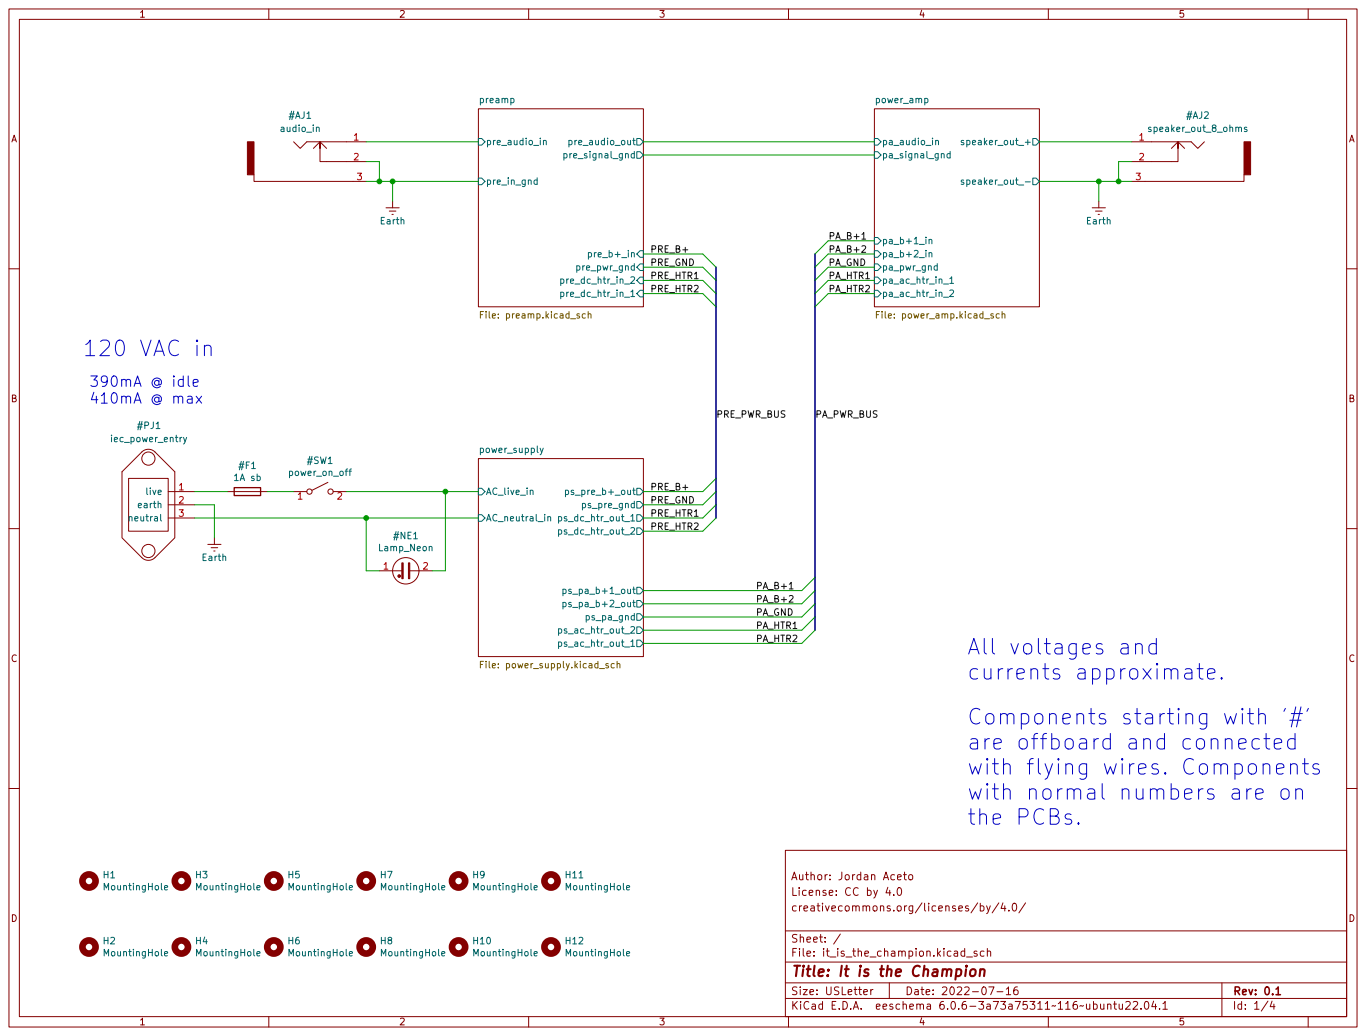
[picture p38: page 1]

All voltages and
currents approximate.
Components starting with '#'
are offboard and connected
with flying wires. Components
with normal numbers are on
the PCBs.

License: CC by 4.0 Author: Jordan Aceto File: it_is_the_champion.kicad_sch Sheet: / creativecommons.org/licenses/by/4.0/

Rev: 0.1 | D Date: 2022-07-16 KiCad E.D.A. eeschema 6.0.6-3a73a75311~116~ubuntu22.04.1 Size: USLetter

Id: 1/4 Title: It is the Champion

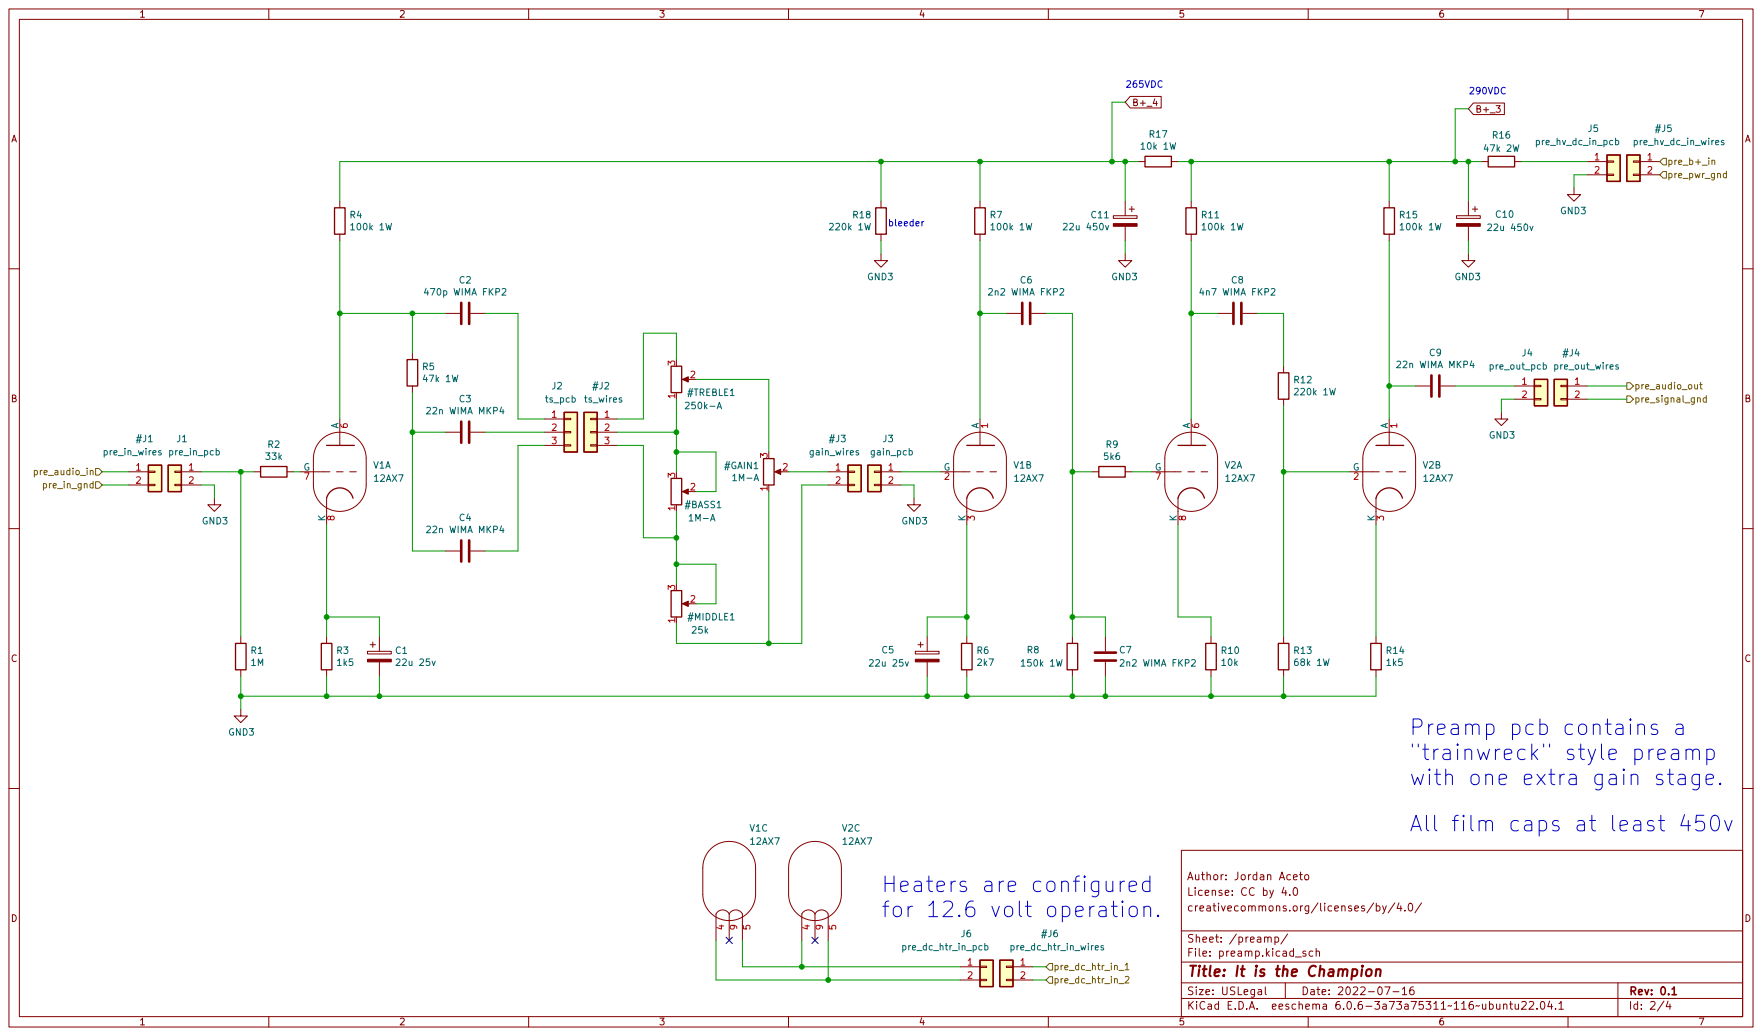
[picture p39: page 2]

Preamp pcb contains a
"trainwreck" style preamp
with one extra gain stage.

License: CC by 4.0 Author: Jordan Aceto

creativecommons.org/licenses/by/4.0/

Rev: 0.1 | D Date: 2022-07-16 KiCad E.D.A. eeschema 6.0.6-3a73a75311~116~ubuntu22.04.1 Size: USLegal

Sheet: /preamp/
File: preamp.kicad_sch
Id: 2/4 Title: It is the Champion

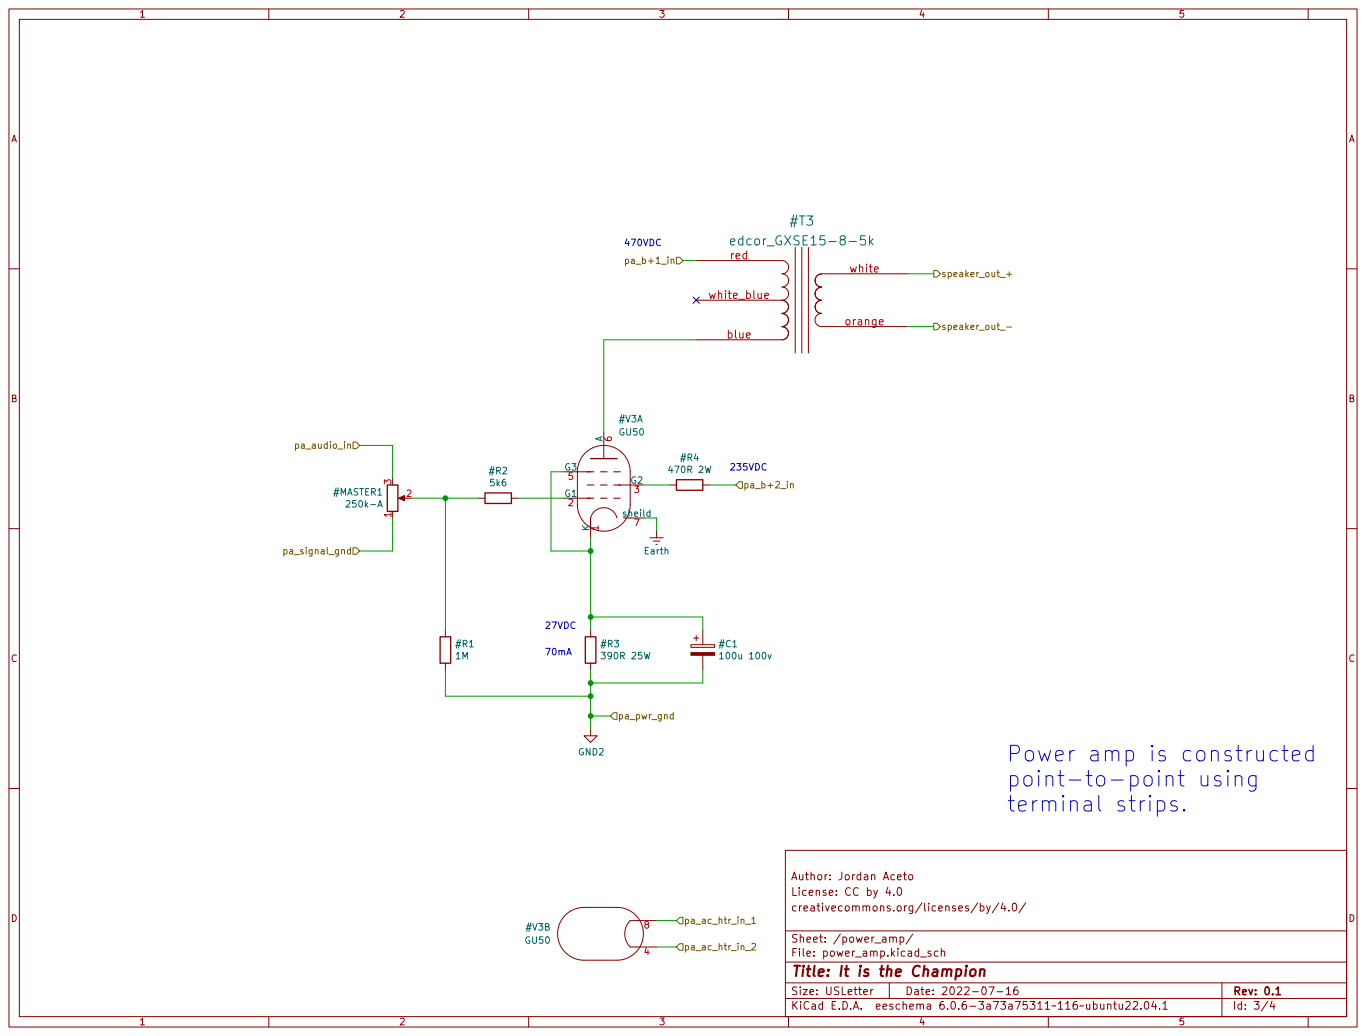
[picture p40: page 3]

point-to-point using
terminal strips.

License: CC by 4.0 Author: Jordan Aceto

creativecommons.org/licenses/by/4.0/

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

Sheet: /power_amp/
File: power_amp.kicad_sch
Id: 3/4 Title: It is the Champion

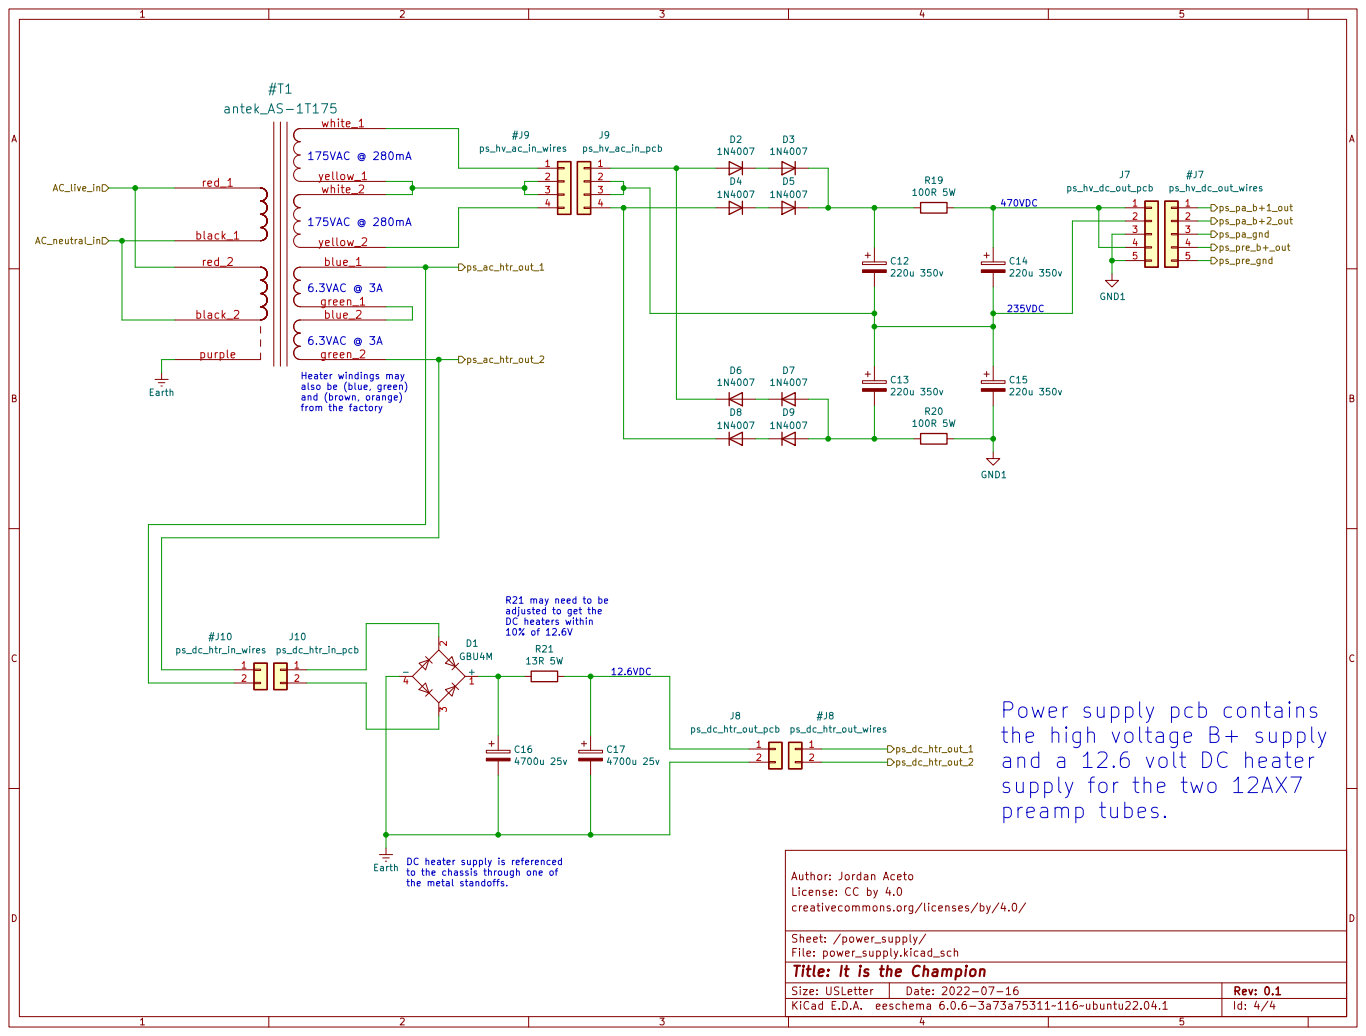
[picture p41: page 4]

10% of 12.6V Heater windings may
also be (blue, green)
and (brown, orange)

R21 may need to be
adjusted to get the DC heaters within

the high voltage B+ supply
and a 12.6 volt DC heater
supply for the two 12AX7
preamp tubes.

DC heater supply is referenced
Earth
to the chassis through one of

License: CC by 4.0 Author: Jordan Aceto

creativecommons.org/licenses/by/4.0/

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

Sheet: /power_supply/
File: power_supply.kicad_sch
Id: 4/4 Title: It is the Champion

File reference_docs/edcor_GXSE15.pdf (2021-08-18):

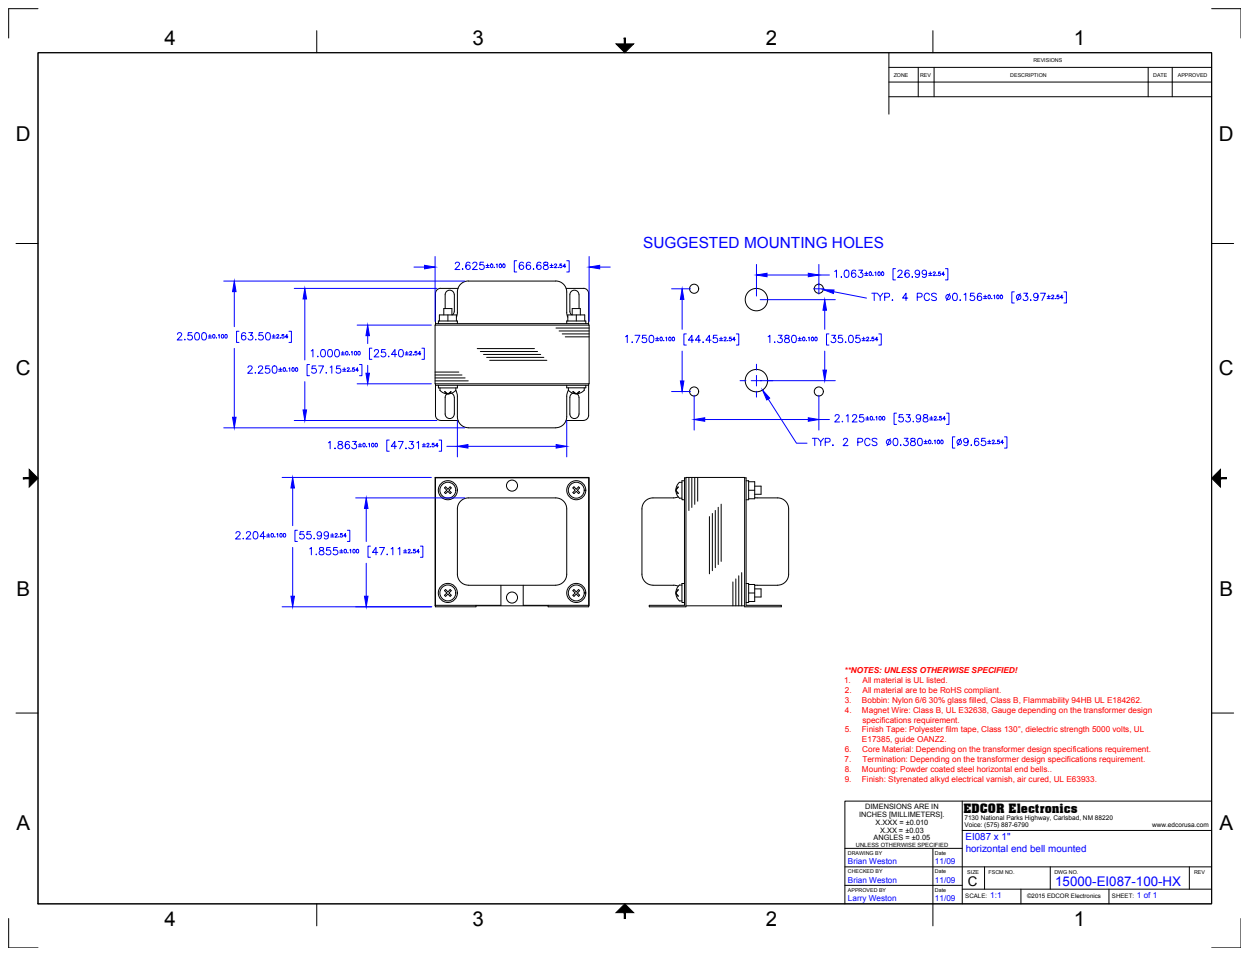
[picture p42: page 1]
SUGGESTED MOUNTING HOLES; C DRAWING BY CHECKED BY APPROVED BY; EDCOR Electronics 7130 National Parks Highway, Carlsbad, NM 88220 ZONE; REV; DESCRIPTION; DATE; APPROVED REVISIONS SIZE; FSCM NO.; DWG NO.; REV SCALE:; SHEET: 15000-EI087-100-HX 1:1; 1 of 1 Larry Weston Brian Weston Brian Weston; Date Date Date 11/09 11/09 11/09 A; www.edcorusa.com BCD; ABCD 4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

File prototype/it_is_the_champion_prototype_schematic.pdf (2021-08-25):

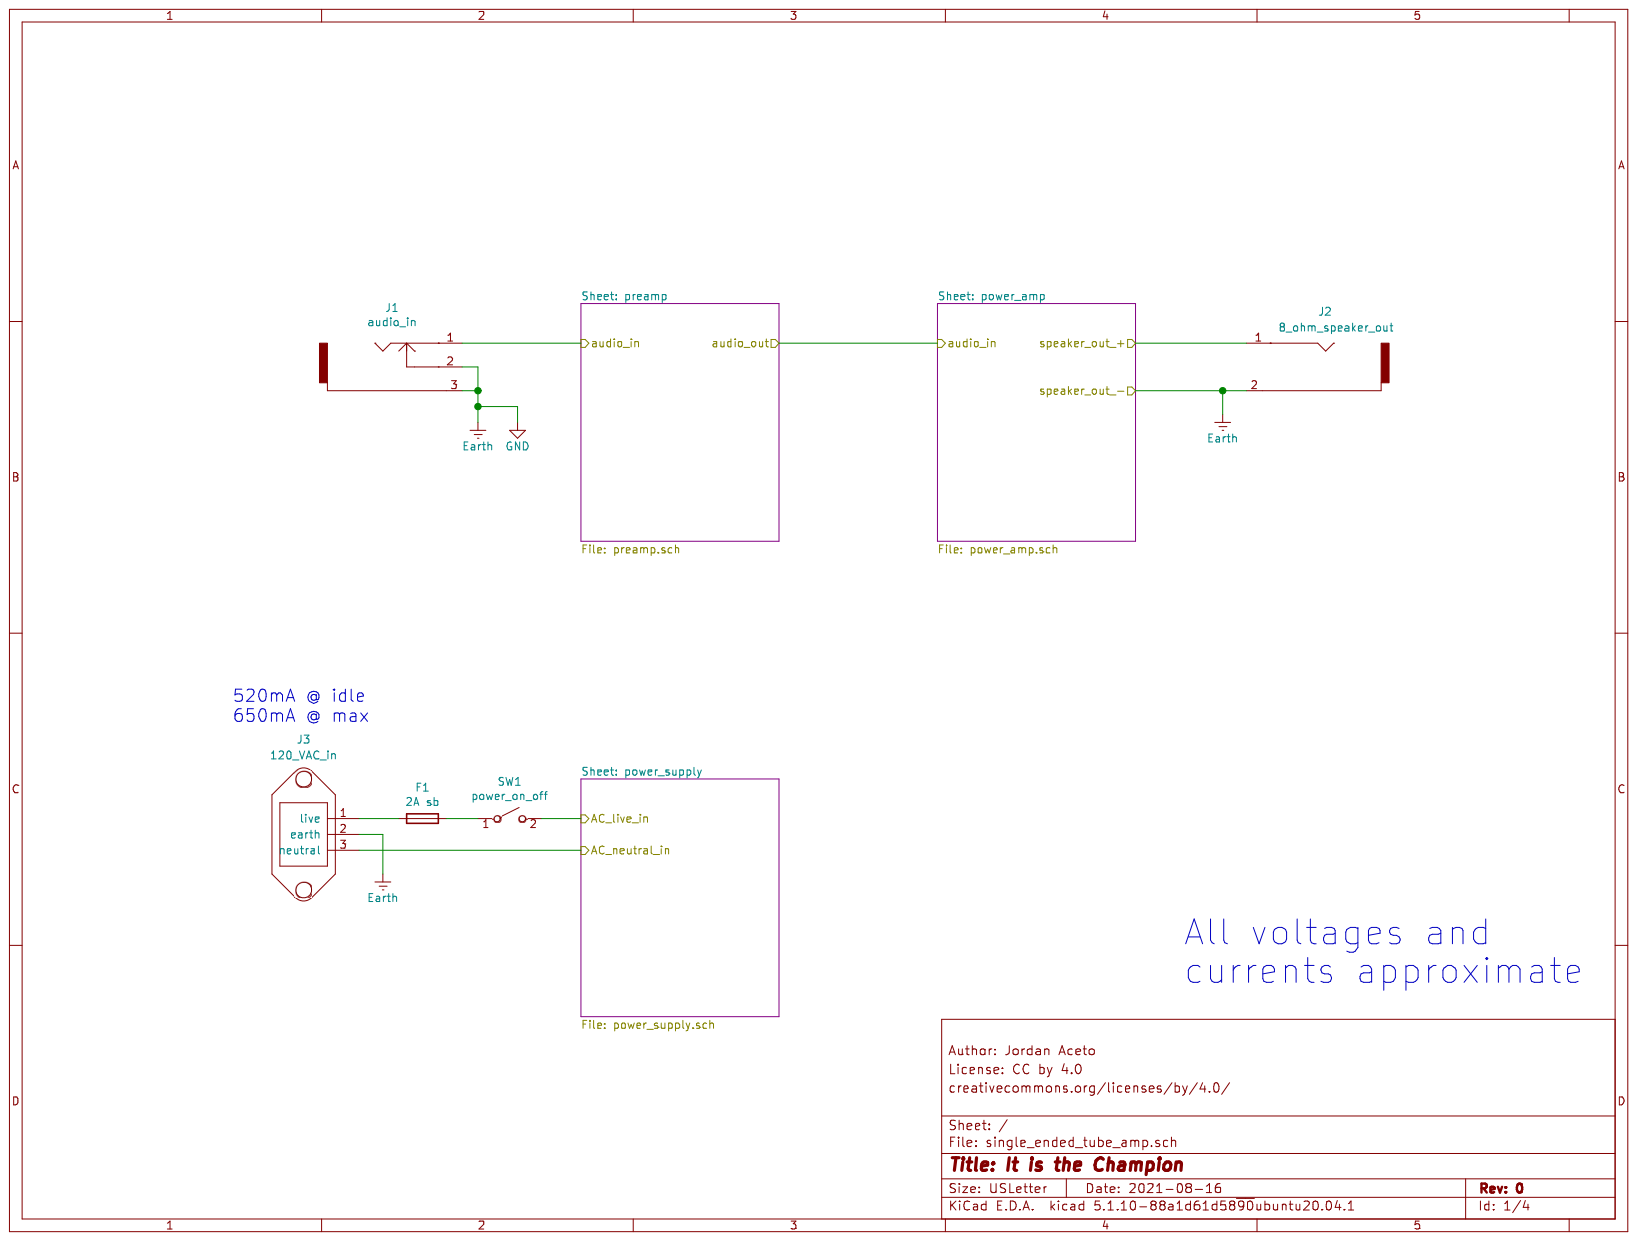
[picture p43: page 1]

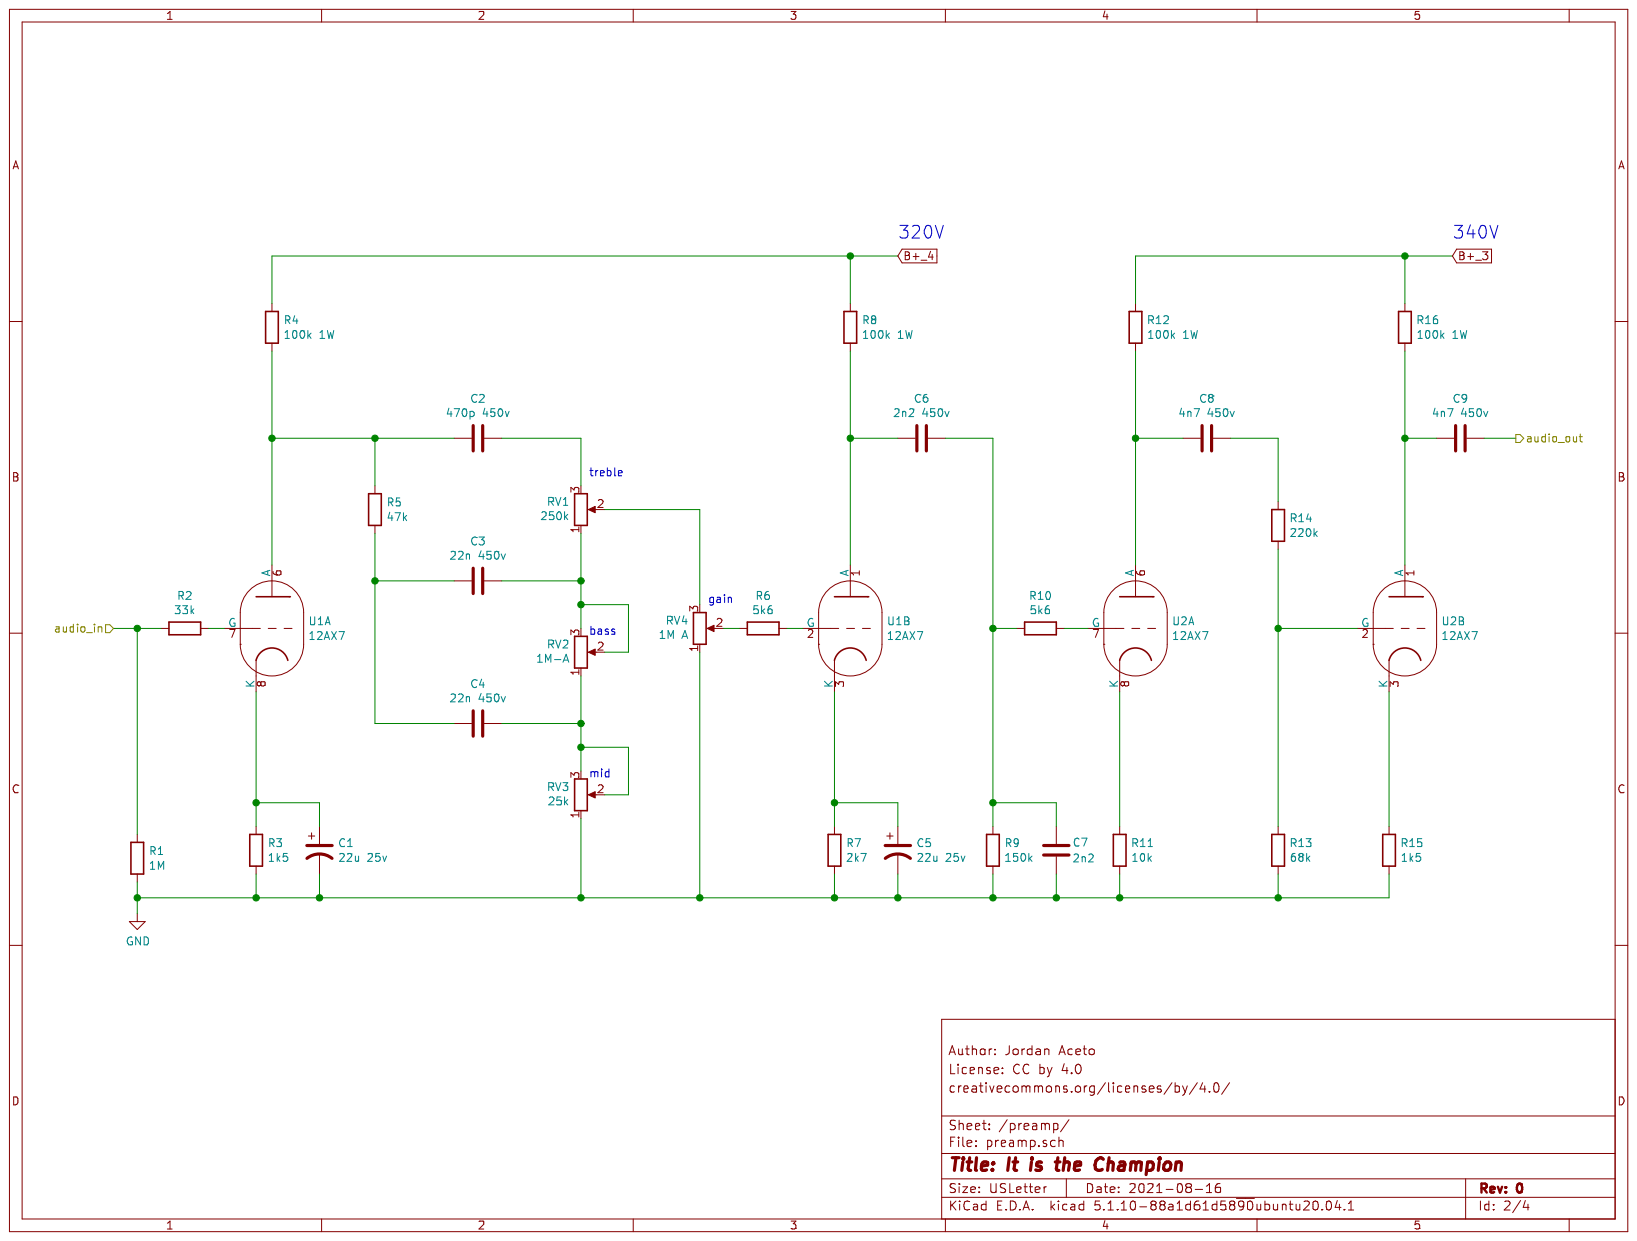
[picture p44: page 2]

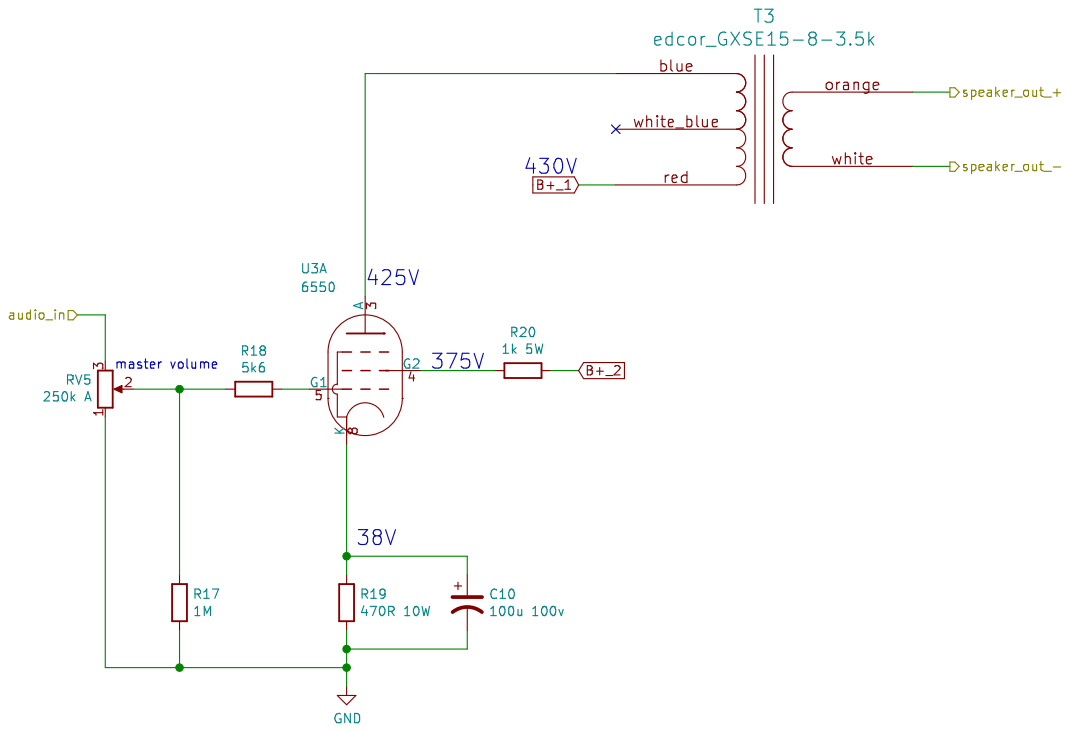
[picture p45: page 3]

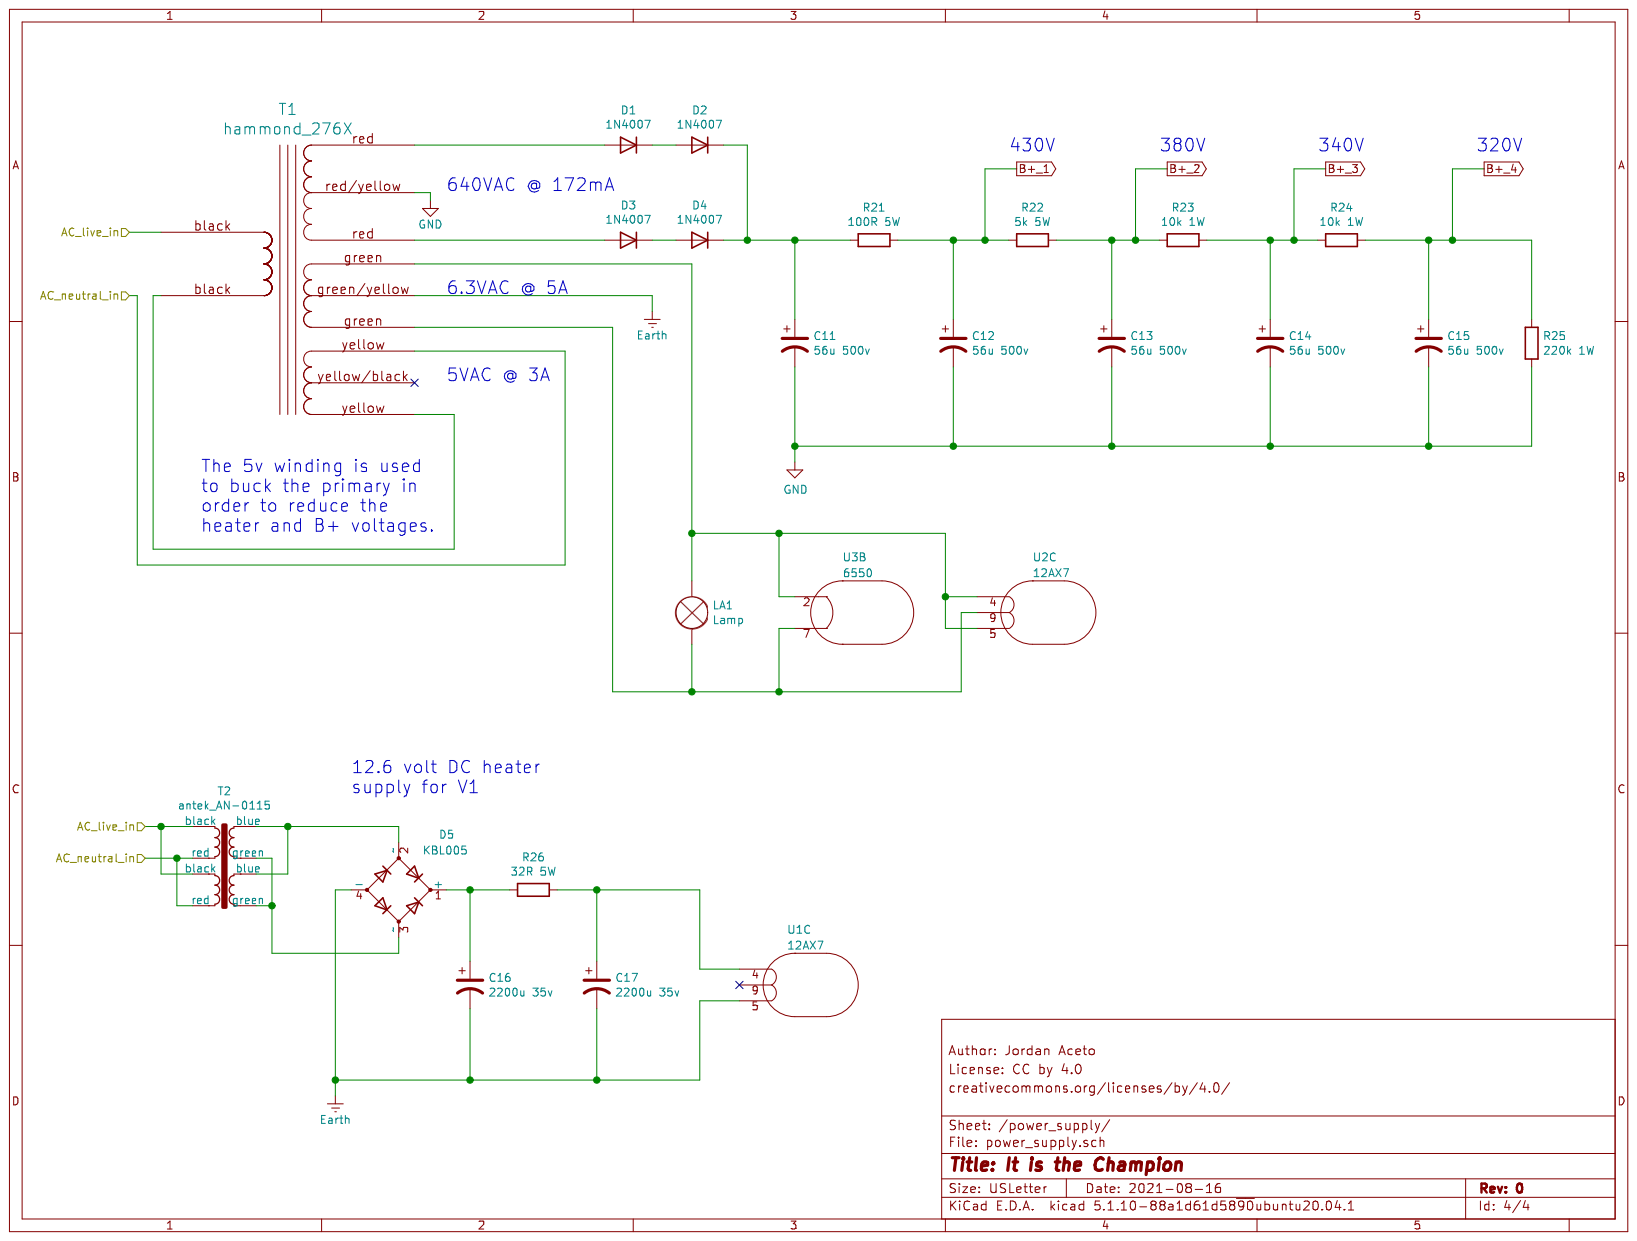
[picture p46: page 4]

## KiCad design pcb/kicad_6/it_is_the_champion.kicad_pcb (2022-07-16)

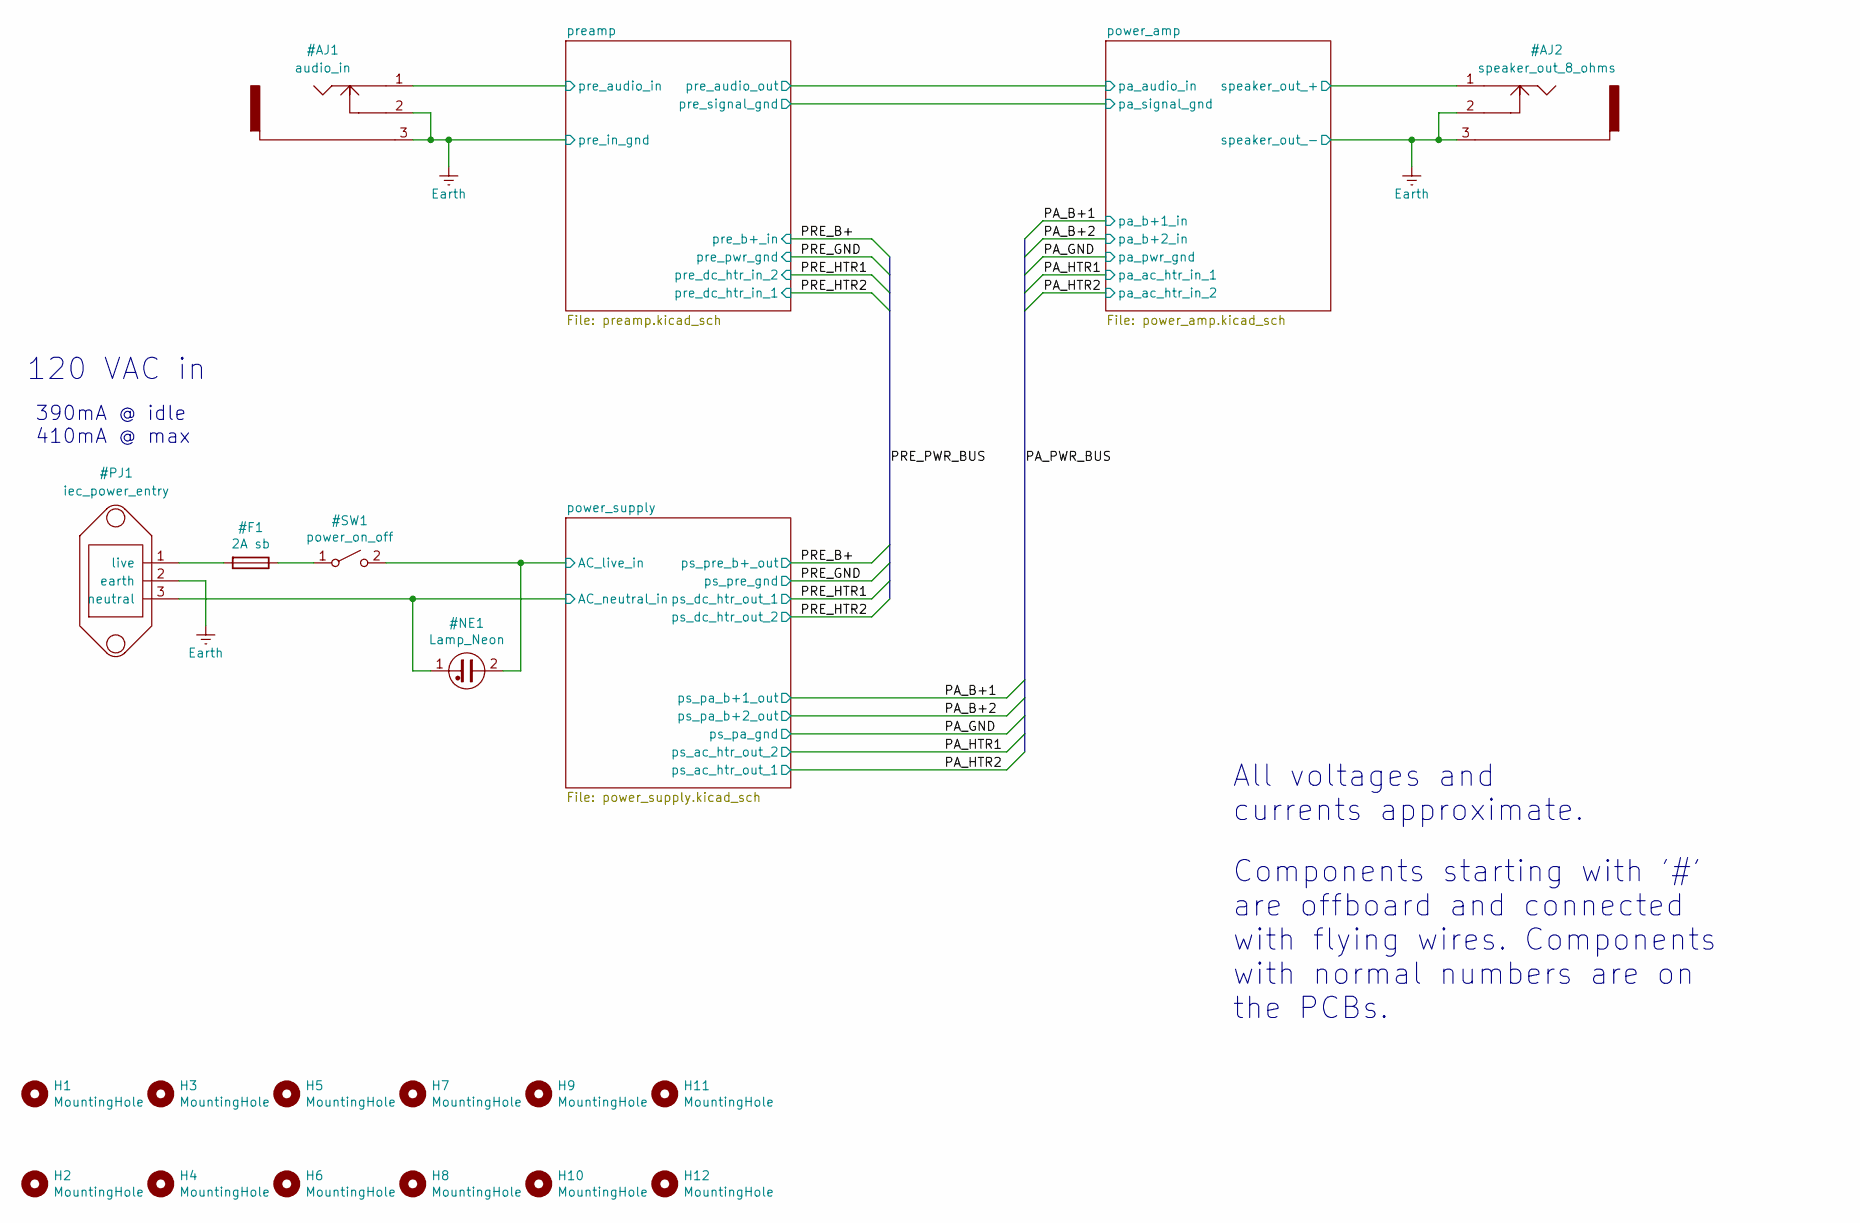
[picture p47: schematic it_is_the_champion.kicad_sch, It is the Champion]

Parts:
H1, H2, H3, H4, H5, H6, H7, H8, H9, H10, H11, H12: MountingHole; MountingHole_3.2mm_M3_DIN965_Pad

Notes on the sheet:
All voltages and currents approximate.
Components starting with '#' are offboard and connected with flying wires. Components with normal numbers are on the PCBs.
120 VAC in
390mA @ idle 410mA @ max

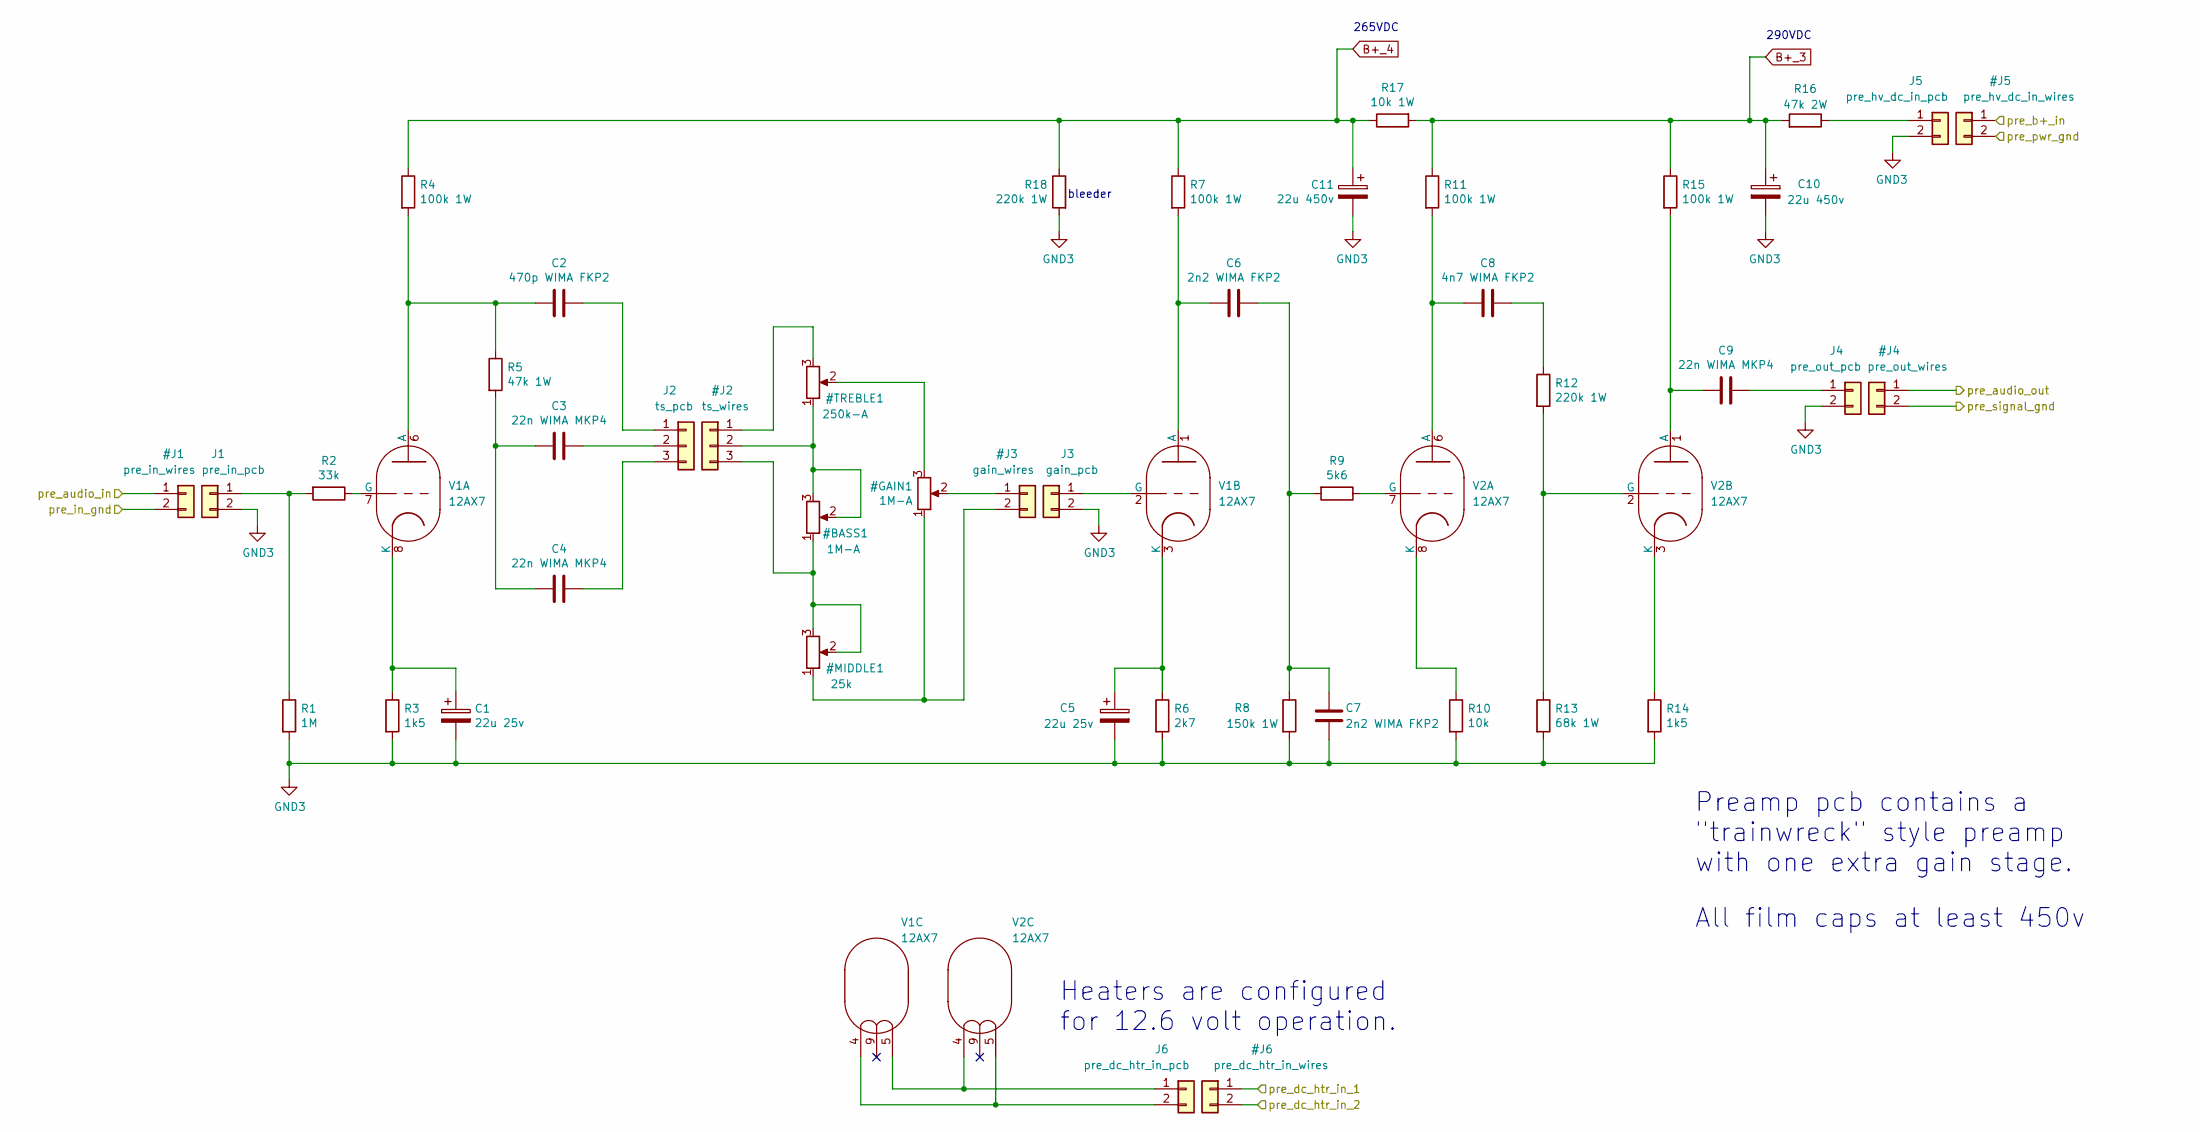
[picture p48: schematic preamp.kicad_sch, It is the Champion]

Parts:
C1, C5: 22u 25v; CP_Radial_D6.3mm_P2.50mm
C2: 470p WIMA FKP2; C_Rect_L7.2mm_W4.5mm_P5.00mm_FKS2_FKP2_MKS2_MKP2
C3, C4, C9: 22n WIMA MKP4; C_Rect_L13.0mm_W4.0mm_P10.00mm_FKS3_FKP3_MKS4
C6, C7: 2n2 WIMA FKP2; C_Rect_L7.2mm_W5.5mm_P5.00mm_FKS2_FKP2_MKS2_MKP2
C8: 4n7 WIMA FKP2; C_Rect_L7.2mm_W7.2mm_P5.00mm_FKS2_FKP2_MKS2_MKP2
C10, C11: 22u 450v; CP_Radial_D18.0mm_P7.50mm
J1: pre_in_pcb; signal_wire_connector_2
J2: ts_pcb; signal_wire_connector_3
J3: gain_pcb; signal_wire_connector_2
J4: pre_out_pcb; signal_wire_connector_2
J5: pre_hv_dc_in_pcb; SolderWire-0.75sqmm_1x02_P4.8mm_D1.25mm_OD2.3mm_Relief
J6: pre_dc_htr_in_pcb; SolderWire-0.75sqmm_1x02_P4.8mm_D1.25mm_OD2.3mm_Relief
R1: 1M; R_Axial_DIN0207_L6.3mm_D2.5mm_P10.16mm_Horizontal
R2: 33k; R_Axial_DIN0207_L6.3mm_D2.5mm_P10.16mm_Horizontal
R3, R14: 1k5; R_Axial_DIN0207_L6.3mm_D2.5mm_P10.16mm_Horizontal
R4, R7, R11, R15: 100k 1W; R_Axial_DIN0414_L11.9mm_D4.5mm_P20.32mm_Horizontal
R5: 47k 1W; R_Axial_DIN0414_L11.9mm_D4.5mm_P20.32mm_Horizontal
R6: 2k7; R_Axial_DIN0207_L6.3mm_D2.5mm_P10.16mm_Horizontal
R8: 150k 1W; R_Axial_DIN0414_L11.9mm_D4.5mm_P20.32mm_Horizontal
R9: 5k6; R_Axial_DIN0207_L6.3mm_D2.5mm_P10.16mm_Horizontal
R10: 10k; R_Axial_DIN0207_L6.3mm_D2.5mm_P10.16mm_Horizontal
R12, R18: 220k 1W; R_Axial_DIN0414_L11.9mm_D4.5mm_P20.32mm_Horizontal
R13: 68k 1W; R_Axial_DIN0414_L11.9mm_D4.5mm_P20.32mm_Horizontal
R16: 47k 2W; R_Axial_DIN0414_L11.9mm_D4.5mm_P20.32mm_Horizontal
R17: 10k 1W; R_Axial_DIN0414_L11.9mm_D4.5mm_P20.32mm_Horizontal
V1, V2: 12AX7; belton_VT9-PT-C

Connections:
B+_3: C10.1, R11.1, R15.1, R16.2, R17.2
B+_4: C11.1, R4.1, R7.1, R17.1, R18.1
GND3: C1.2, C5.2, C7.2, C10.2, C11.2, J1.2, J3.2, J4.2, J5.2, R1.2, R3.2, R6.2, R8.2, R10.2, R13.2, R14.2, R18.2
unnamed: C1.1, R3.1, V1.8 (K)
unnamed: C2.1, J2.1
unnamed: C2.2, R4.2, R5.1, V1.6 (A)
unnamed: C3.1, J2.2
unnamed: C3.2, C4.2, R5.2
unnamed: C4.1, J2.3
unnamed: C5.1, R6.1, V1.3 (K)
unnamed: C6.1, C7.1, R8.1, R9.2
unnamed: C6.2, R7.2, V1.1 (A)
unnamed: C8.1, R12.1
unnamed: C8.2, R11.2, V2.6 (A)
unnamed: C9.1, J4.1
unnamed: C9.2, R15.2, V2.1 (A)
unnamed: J1.1, R1.1, R2.2
unnamed: J3.1, V1.2 (G)
unnamed: J5.1, R16.1
unnamed: J6.1, V1.5, V2.4
unnamed: J6.2, V1.4, V2.5
unnamed: R2.1, V1.7 (G)
unnamed: R9.1, V2.7 (G)
unnamed: R10.1, V2.8 (K)
unnamed: R12.2, R13.1, V2.2 (G)
unnamed: R14.1, V2.3 (K)

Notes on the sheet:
Preamp pcb contains a "trainwreck" style preamp with one extra gain stage.
bleeder
Heaters are configured for 12.6 volt operation.
290VDC
265VDC
All film caps at least 450v

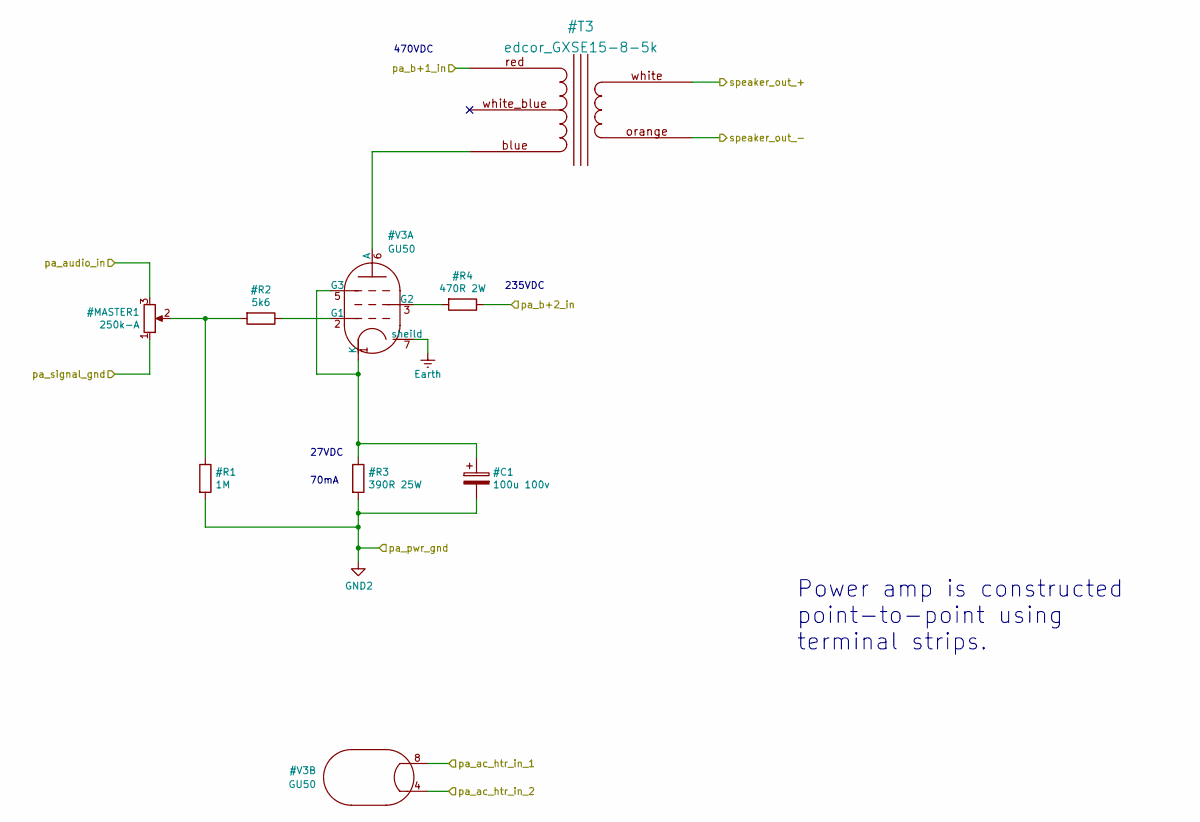
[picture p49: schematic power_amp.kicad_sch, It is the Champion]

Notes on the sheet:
470VDC
235VDC
70mA
27VDC
Power amp is constructed point-to-point using terminal strips.

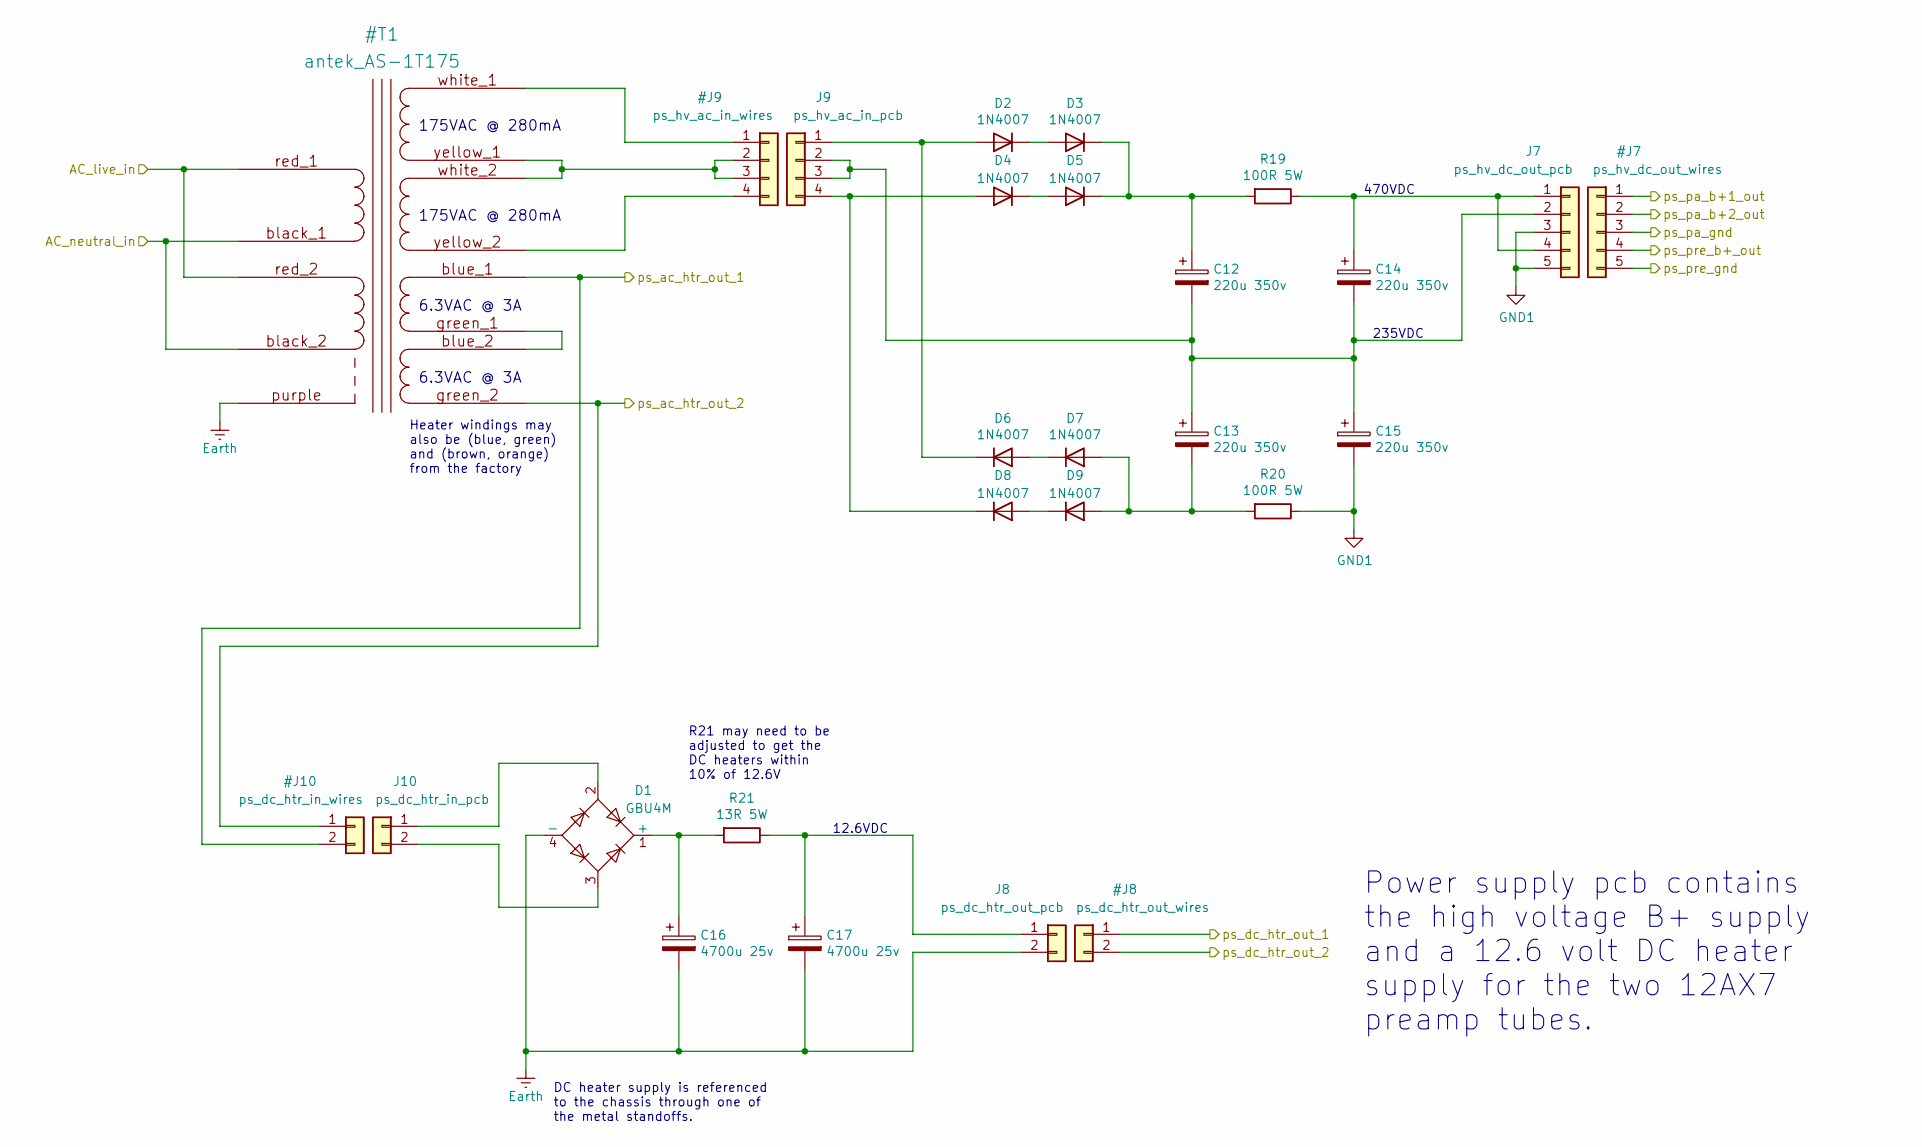
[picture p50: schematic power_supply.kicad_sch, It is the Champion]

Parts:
C12, C13, C14, C15: 220u 350v; CP_Radial_D18.0mm_P7.50mm
C16, C17: 4700u 25v; CP_Radial_D16.0mm_P7.50mm
D1: GBU4M; Diode_Bridge_Vishay_GBU
D2, D3, D4, D5, D6, D7, D8, D9: 1N4007; D_DO-41_SOD81_P10.16mm_Horizontal
J7: ps_hv_dc_out_pcb; SolderWire-0.75sqmm_1x05_P4.8mm_D1.25mm_OD2.3mm_Relief
J8: ps_dc_htr_out_pcb; SolderWire-0.75sqmm_1x02_P4.8mm_D1.25mm_OD2.3mm_Relief
J9: ps_hv_ac_in_pcb; SolderWire-0.75sqmm_1x04_P4.8mm_D1.25mm_OD2.3mm_Relief
J10: ps_dc_htr_in_pcb; SolderWire-0.75sqmm_1x02_P4.8mm_D1.25mm_OD2.3mm_Relief
R19, R20: 100R 5W; R_Axial_DIN0617_L17.0mm_D6.0mm_P30.48mm_Horizontal
R21: 13R 5W; R_Axial_DIN0617_L17.0mm_D6.0mm_P30.48mm_Horizontal

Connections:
Earth: C16.2, C17.2, D1.4 (-), J8.2
GND1: C15.2, J7.3, J7.5, R20.1
unnamed: C12.1, D3.1 (K), D5.1 (K), R19.2
unnamed: C12.2, C13.1, C14.2, C15.1, J7.2, J9.2, J9.3
unnamed: C13.2, D7.2 (A), D9.2 (A), R20.2
unnamed: C14.1, J7.1, J7.4, R19.1
unnamed: C16.1, D1.1 (+), R21.2
unnamed: C17.1, J8.1, R21.1
unnamed: D1.2, J10.1
unnamed: D1.3, J10.2
unnamed: D2.1 (K), D3.2 (A)
unnamed: D2.2 (A), D6.1 (K), J9.1
unnamed: D4.1 (K), D5.2 (A)
unnamed: D4.2 (A), D8.1 (K), J9.4
unnamed: D6.2 (A), D7.1 (K)
unnamed: D8.2 (A), D9.1 (K)

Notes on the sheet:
175VAC @ 280mA
470VDC
12.6VDC
DC heater supply is referenced to the chassis through one of the metal standoffs.
6.3VAC @ 3A
R21 may need to be adjusted to get the DC heaters within 10% of 12.6V
Power supply pcb contains the high voltage B+ supply and a 12.6 volt DC heater supply for the two 12AX7 preamp tubes.
Heater windings may also be (blue, green) and (brown, orange) from the factory
235VDC

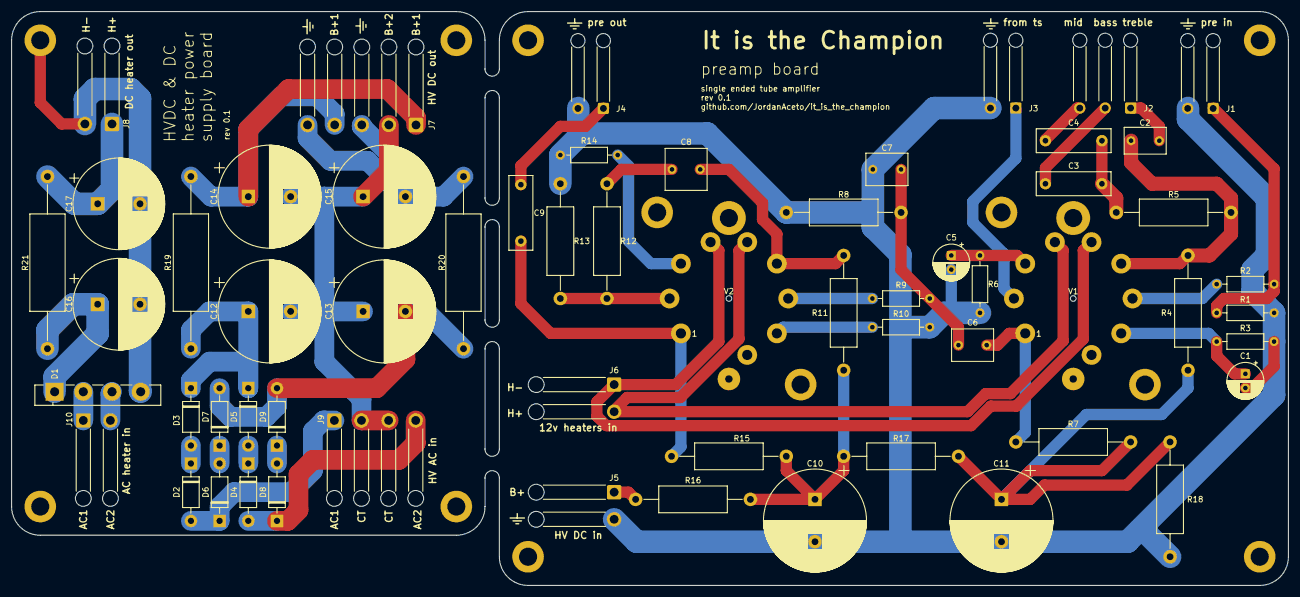
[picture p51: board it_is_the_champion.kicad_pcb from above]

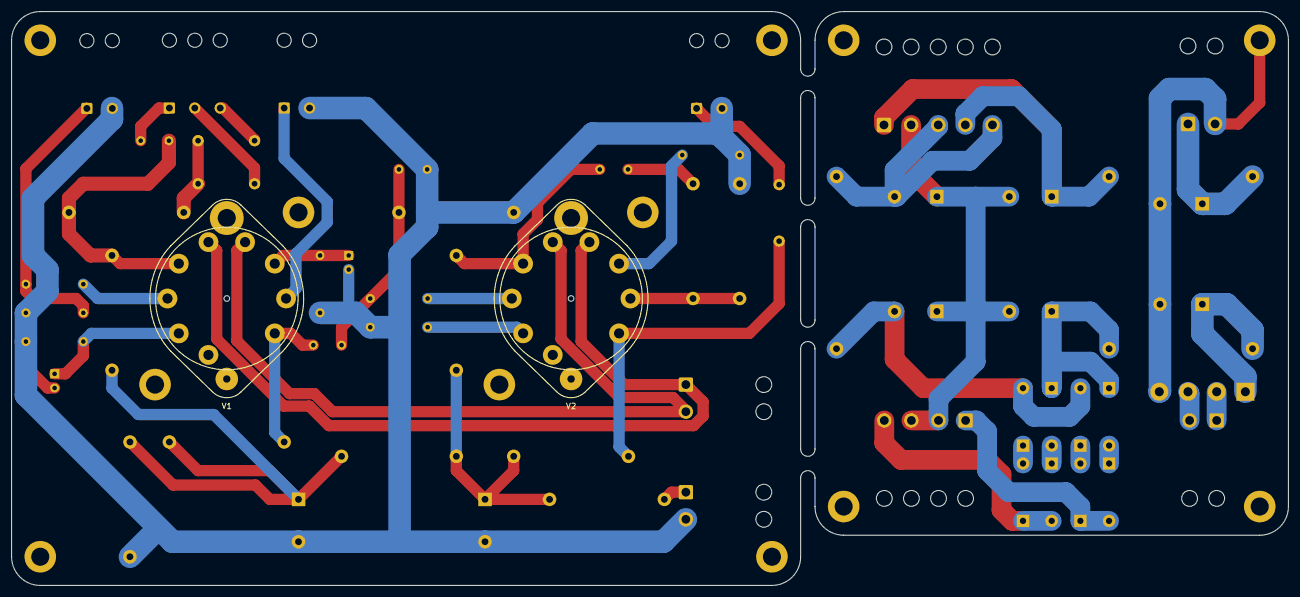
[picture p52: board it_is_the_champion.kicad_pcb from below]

Board: 2 copper layers, 226.1 x 101.6 mm, 71 parts (2 on the bottom side), 42 nets.

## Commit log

2021-08-18 move schematic to top level
2021-08-18 tweak DC heater, pcb, regenerate build files
    [power_supply.sch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]
2021-08-19 start write-up for prototype evaluation
2021-08-19 reduce gain in last preamp stage
    [preamp.sch]
2021-08-25 tweak prototype, add to proto write-up
    [preamp.sch]
2021-12-13 change PA to GU50, respin pcb
    [it_is_the_champion-B_Cu.gbl, it_is_the_champion-B_Mask.gbs, it_is_the_champion-B_Paste.gbp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]
2021-12-21 add screen wire to power xformer
    [it_is_the_champion.sch, power_amp.sch, power_supply.sch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]
2021-12-30 rear panel organization, gerbers
    [it_is_the_champion_rear_panel-B_Cu.gbl, it_is_the_champion_rear_panel-B_Mask.gbs, it_is_the_champion_rear_panel-B_Paste.gbp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]
2021-12-30 update gitignore for kicad 6
2021-12-30 update pcb for kicad 6
2021-12-30 moce schematic, update readme
2021-12-31 fix capacitor name typo
    [it_is_the_champion.kicad_pcb, it_is_the_champion.kicad_sch, power_amp.kicad_sch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]
2021-12-31 update faceplate dir for kicad 6, add warnings
    [it_is_the_champion_facplate.kicad_pcb, it_is_the_champion_facplate.kicad_sch, single_ended_tube_amp_faceplate-B_Cu.gbl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]
2022-01-04 tweak some values
    [it_is_the_champion.kicad_pcb, it_is_the_champion.kicad_sch, power_amp.kicad_sch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]
2022-07-16 Update faceplate and rear panel
    [it_is_the_champion_faceplate-3D.step, it_is_the_champion_faceplate-B_Cu.dxf, it_is_the_champion_faceplate-B_Silkscreen.dxf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]
2022-07-16 Improve pcb documentation
    [it_is_the_champion-3D.step, it_is_the_champion-B_Cu.dxf, it_is_the_champion-B_Mask.dxf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]
2022-07-16 Tweaks to KiCad pcb project
    [it_is_the_champion.kicad_pcb, it_is_the_champion.kicad_sch, power_amp.kicad_sch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]
